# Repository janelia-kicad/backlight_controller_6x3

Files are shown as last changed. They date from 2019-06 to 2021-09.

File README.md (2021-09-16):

- [Repository Information](#org89e2f96)
  - [Description](#org01946da)
- [Images](#org5e6b005)
- [Schematic](#org50048ed)
- [Gerbers](#org1f83db4)
- [Bill of Materials](#org4e1d2f2)
  - [PCB Parts](#org0365191)
  - [Supplemental Parts](#org1217ce1)
  - [Vendor Parts Lists](#orge2d2bad)
- [Supplemental Documentation](#org1794ae5)
  - [Assembly Instructions](#orgcad51c4)
- [Manufacturing Archive](#orgdf269ab)

# Repository Information

-   **Name:** backlight\_controller\_6x3
-   **Version:** 1.0
-   **License:** Open-Source Hardware
-   **URL:** <https://github.com/janelia-kicad/backlight_controller_6x3>
-   **Author:** Peter Polidoro
-   **Email:** peter@polidoro.io

## Description

This board controls up to four Smart Vision backlights with IR and visible channels plus additional high and low power channel outputs.

# Images

# Schematic

[./schematic/backlight\_controller\_6x3.pdf](./schematic/backlight_controller_6x3.pdf)

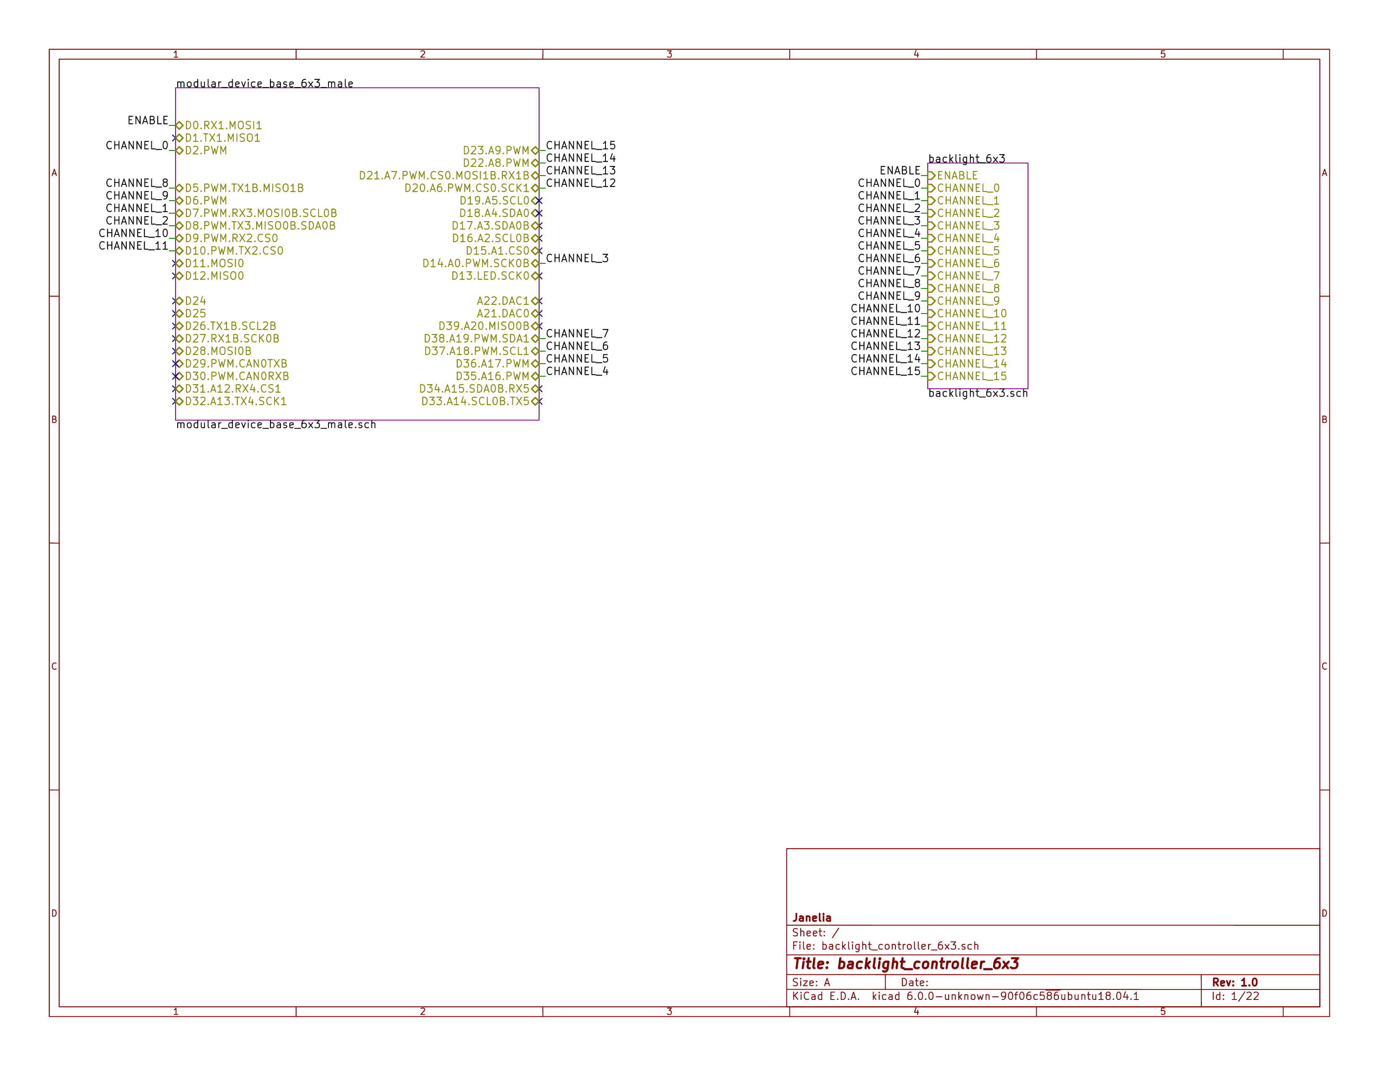
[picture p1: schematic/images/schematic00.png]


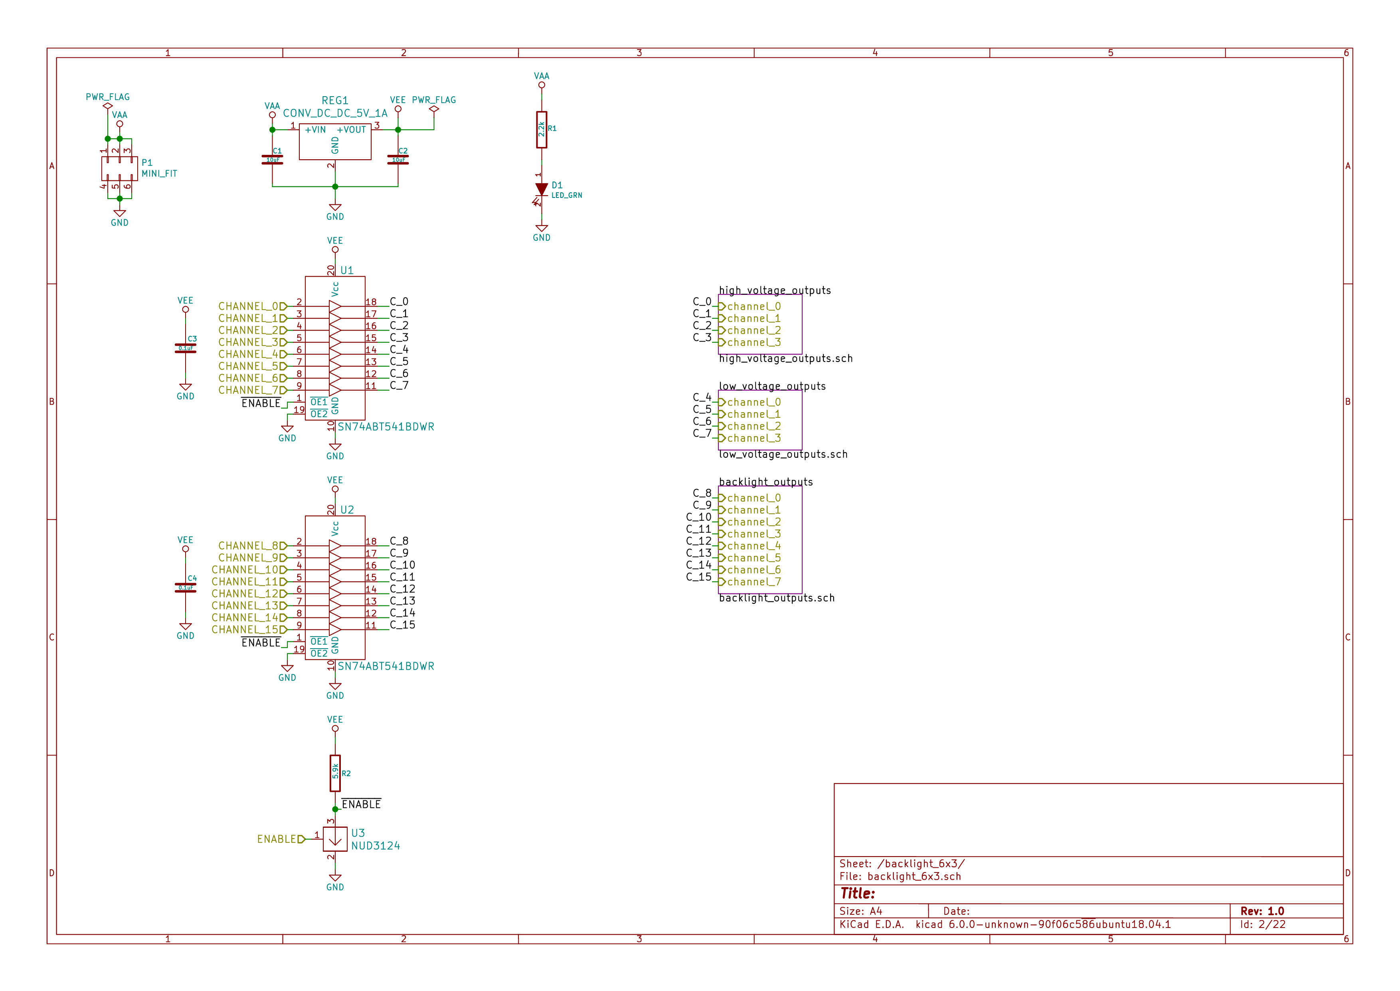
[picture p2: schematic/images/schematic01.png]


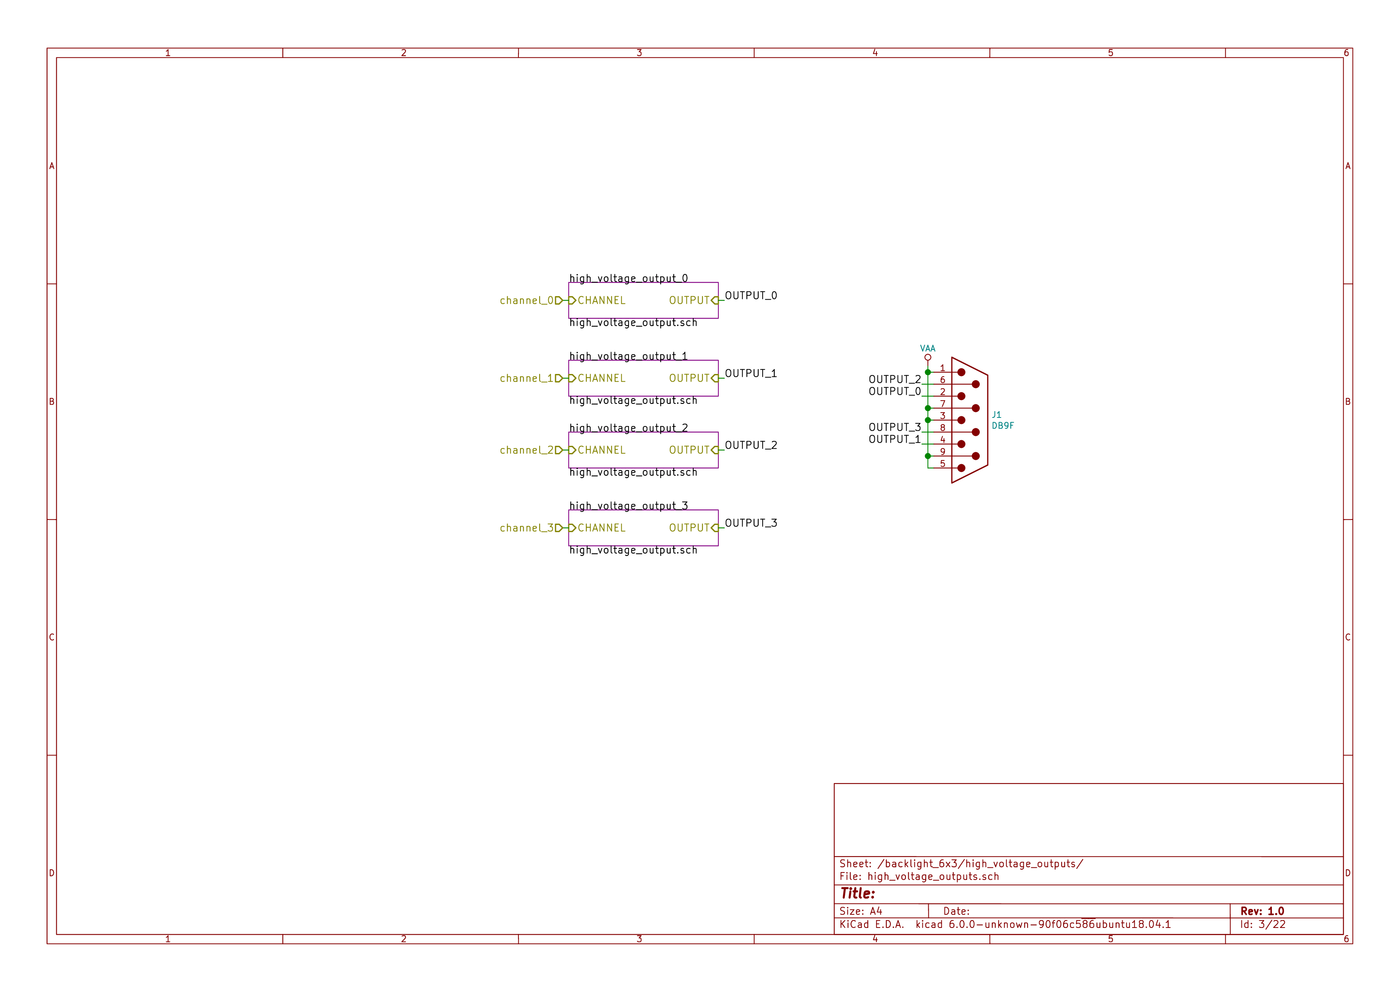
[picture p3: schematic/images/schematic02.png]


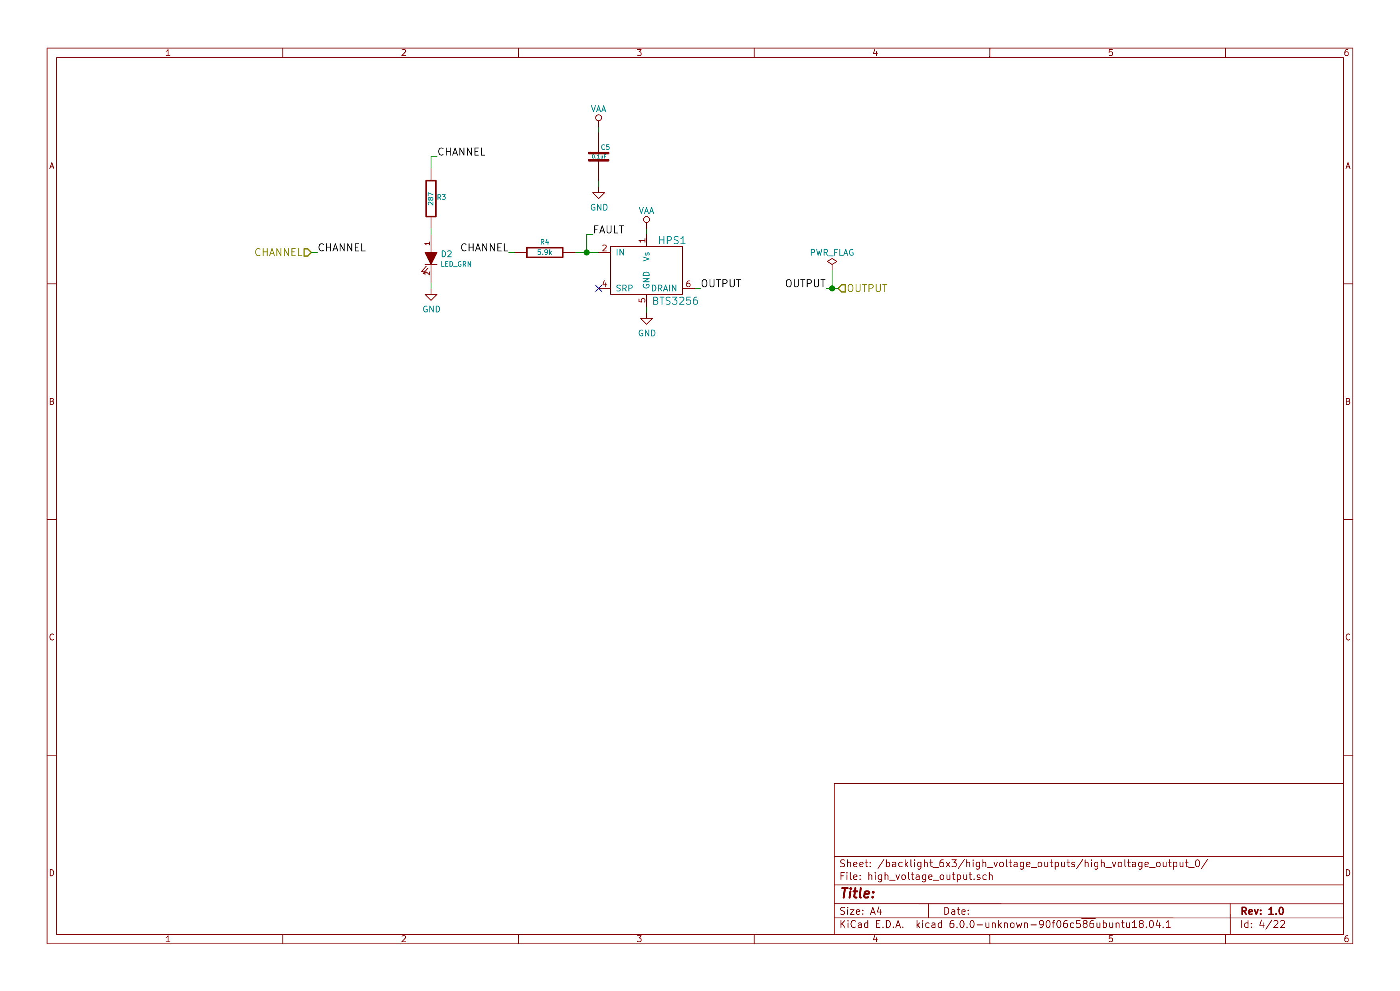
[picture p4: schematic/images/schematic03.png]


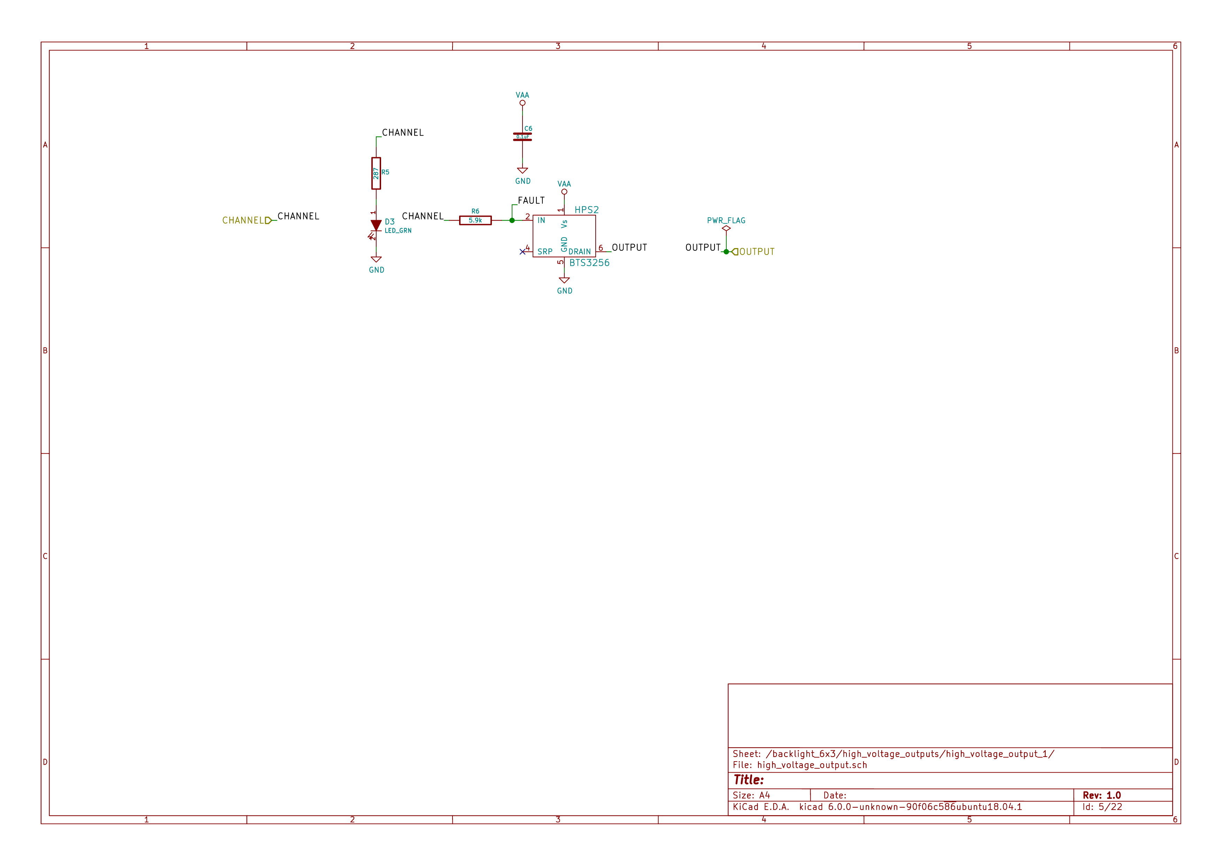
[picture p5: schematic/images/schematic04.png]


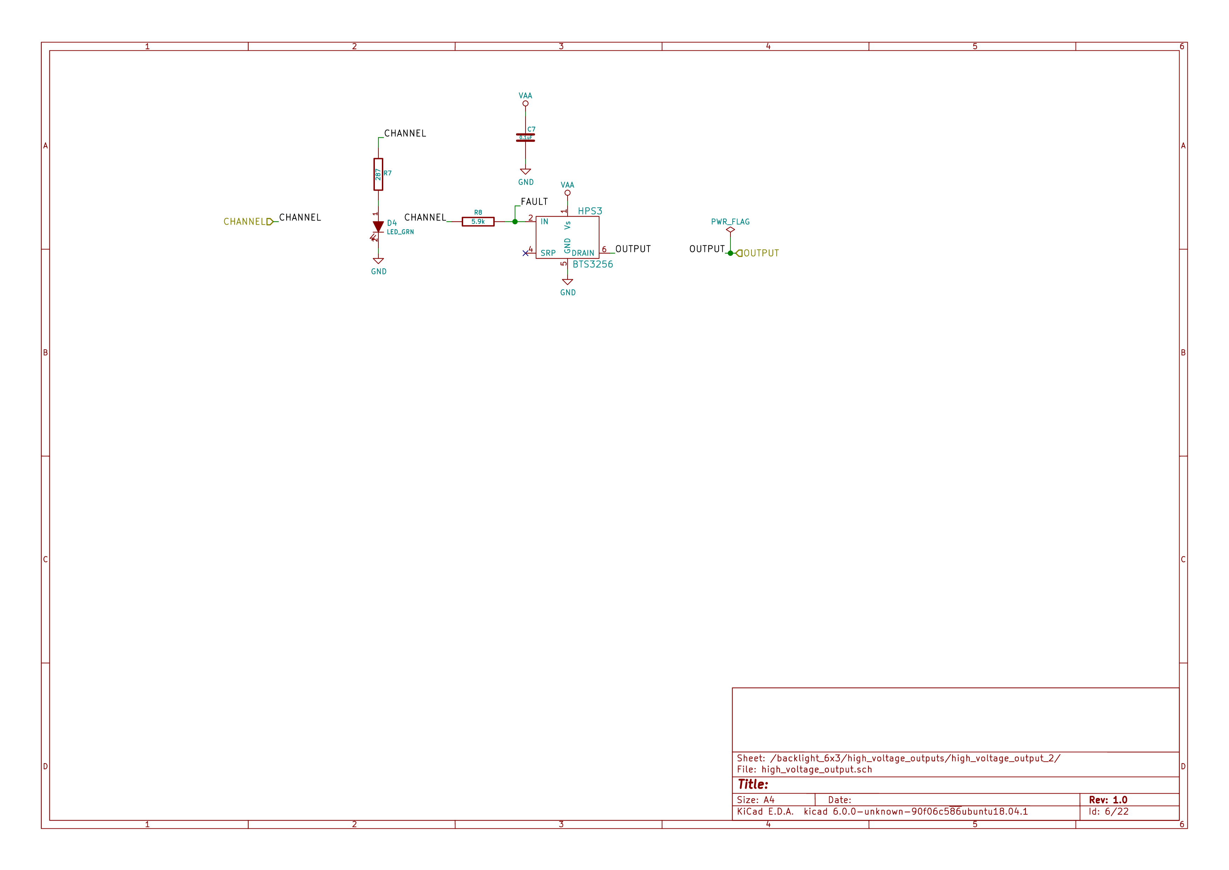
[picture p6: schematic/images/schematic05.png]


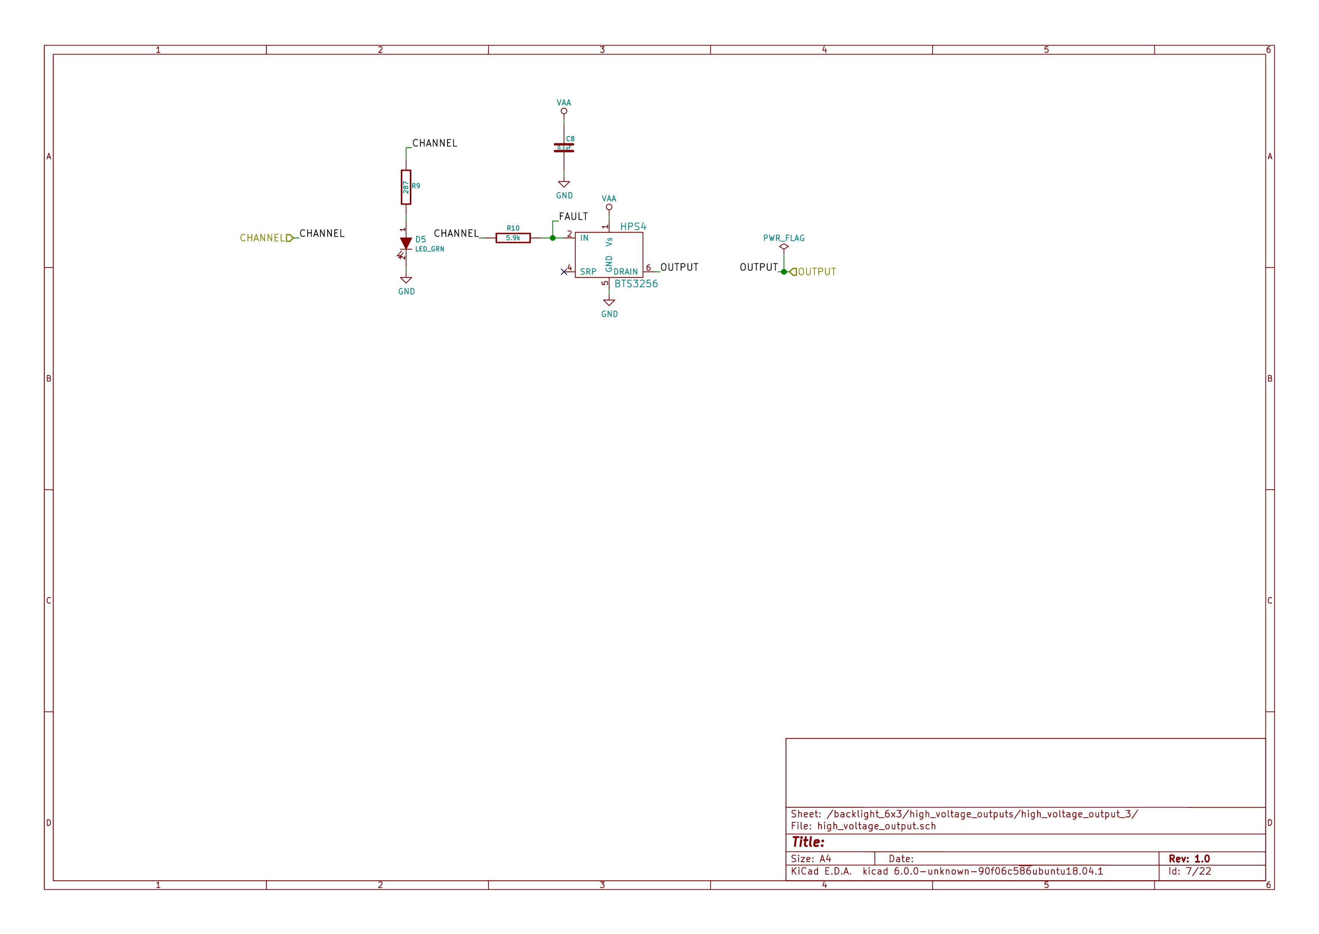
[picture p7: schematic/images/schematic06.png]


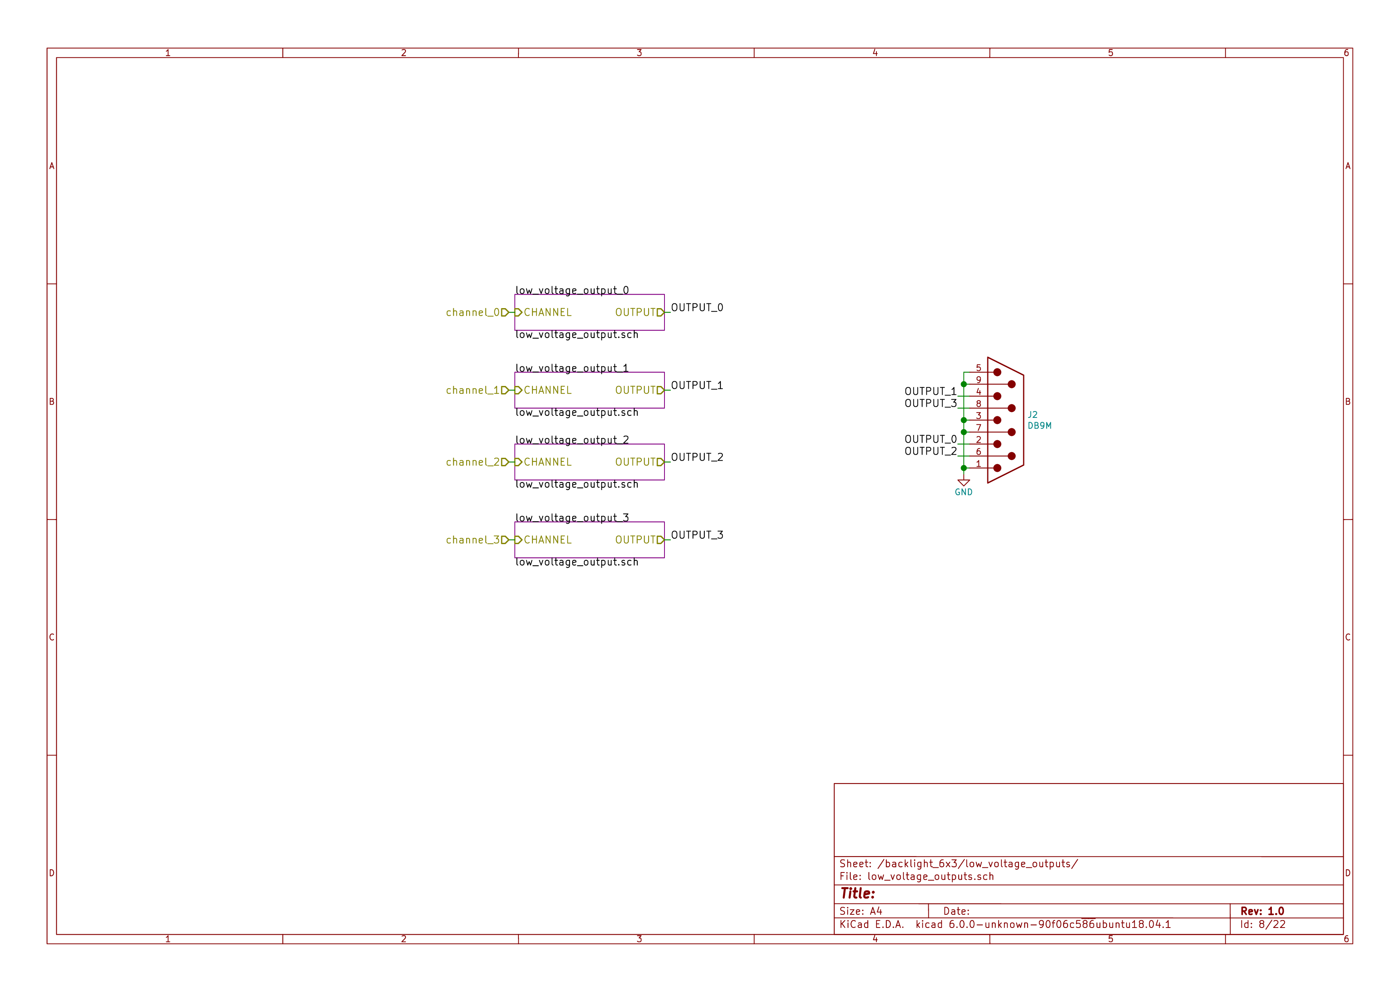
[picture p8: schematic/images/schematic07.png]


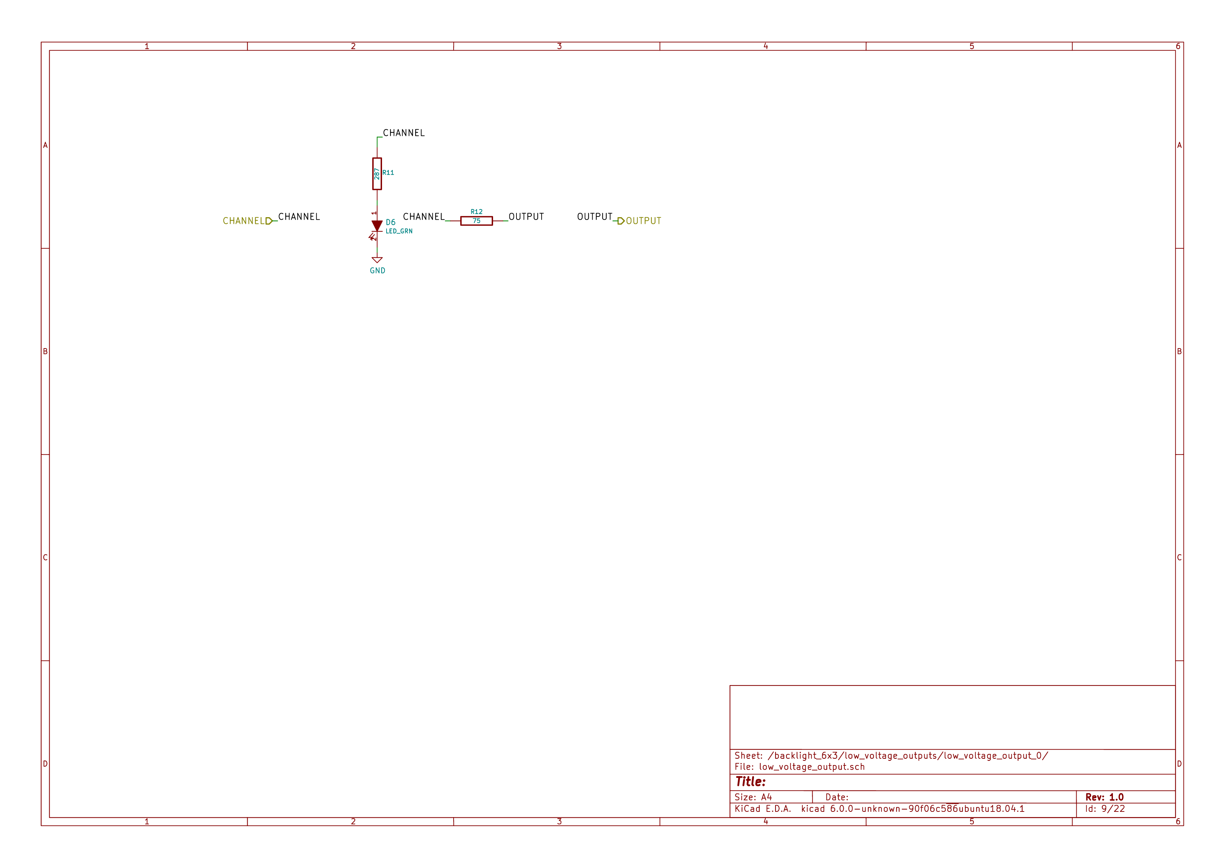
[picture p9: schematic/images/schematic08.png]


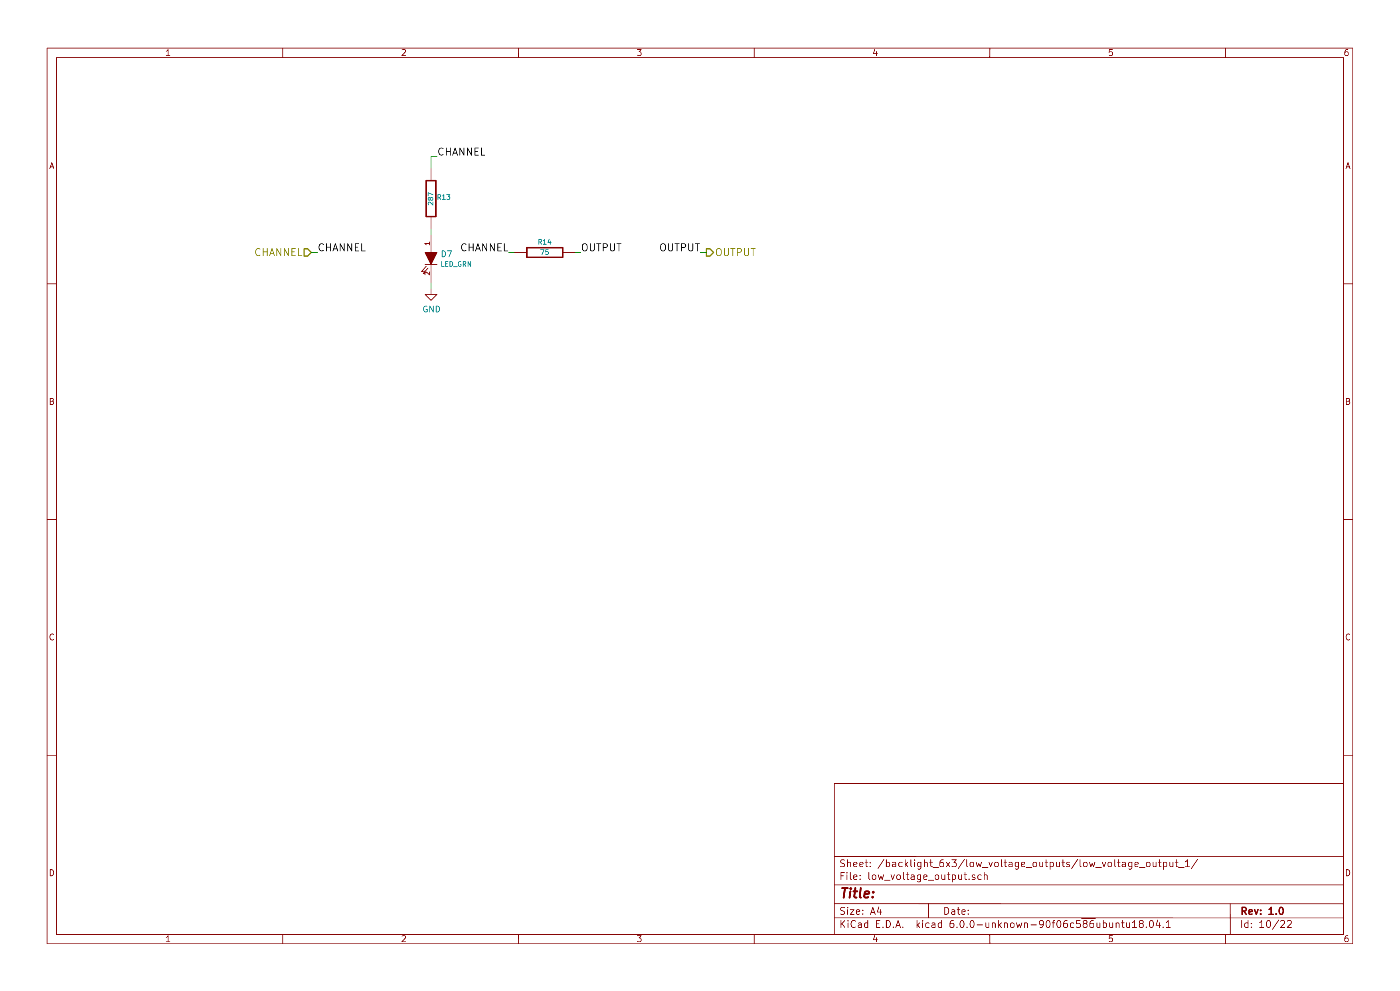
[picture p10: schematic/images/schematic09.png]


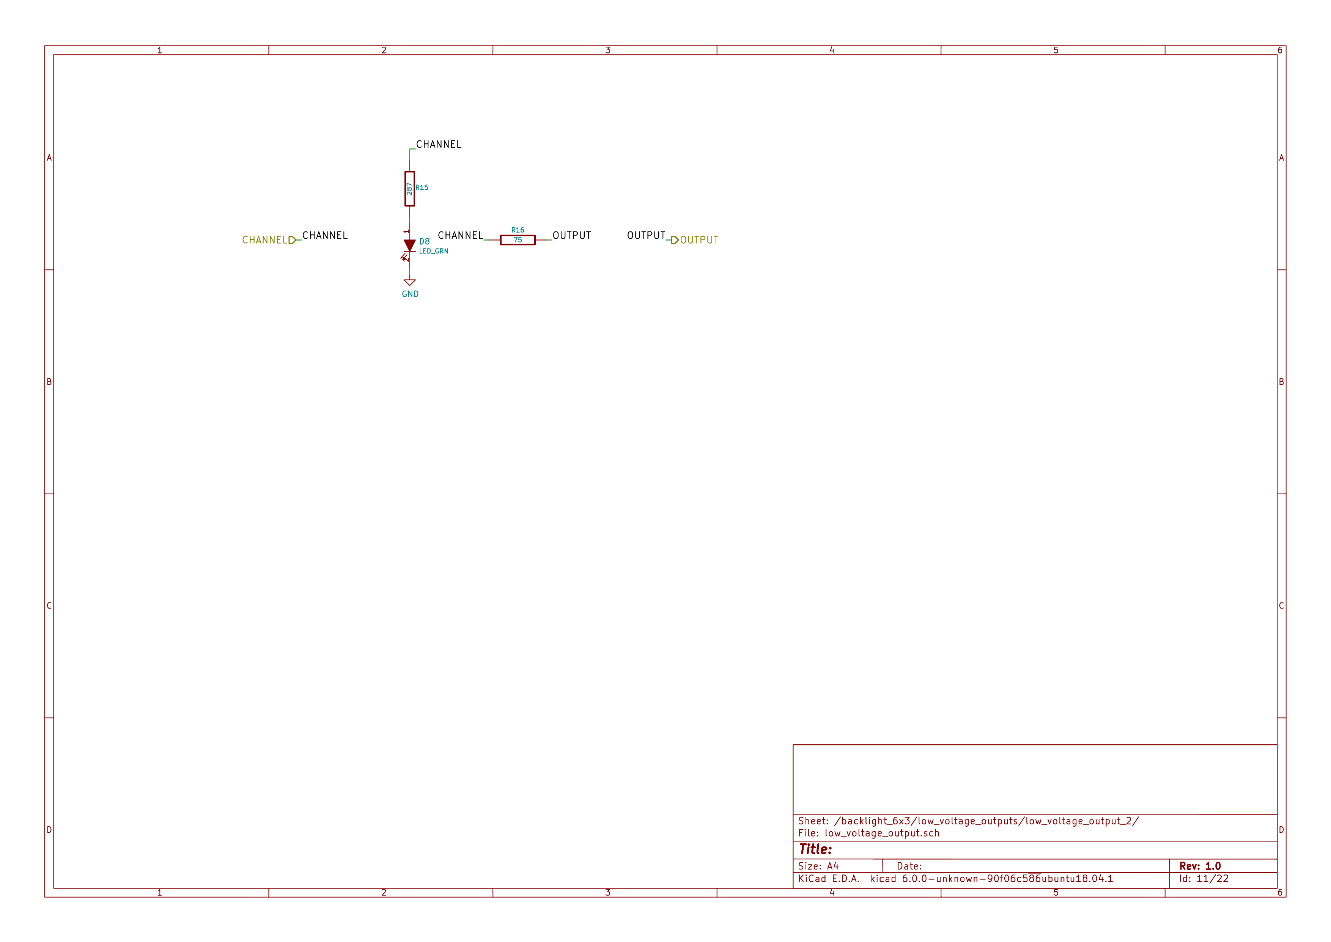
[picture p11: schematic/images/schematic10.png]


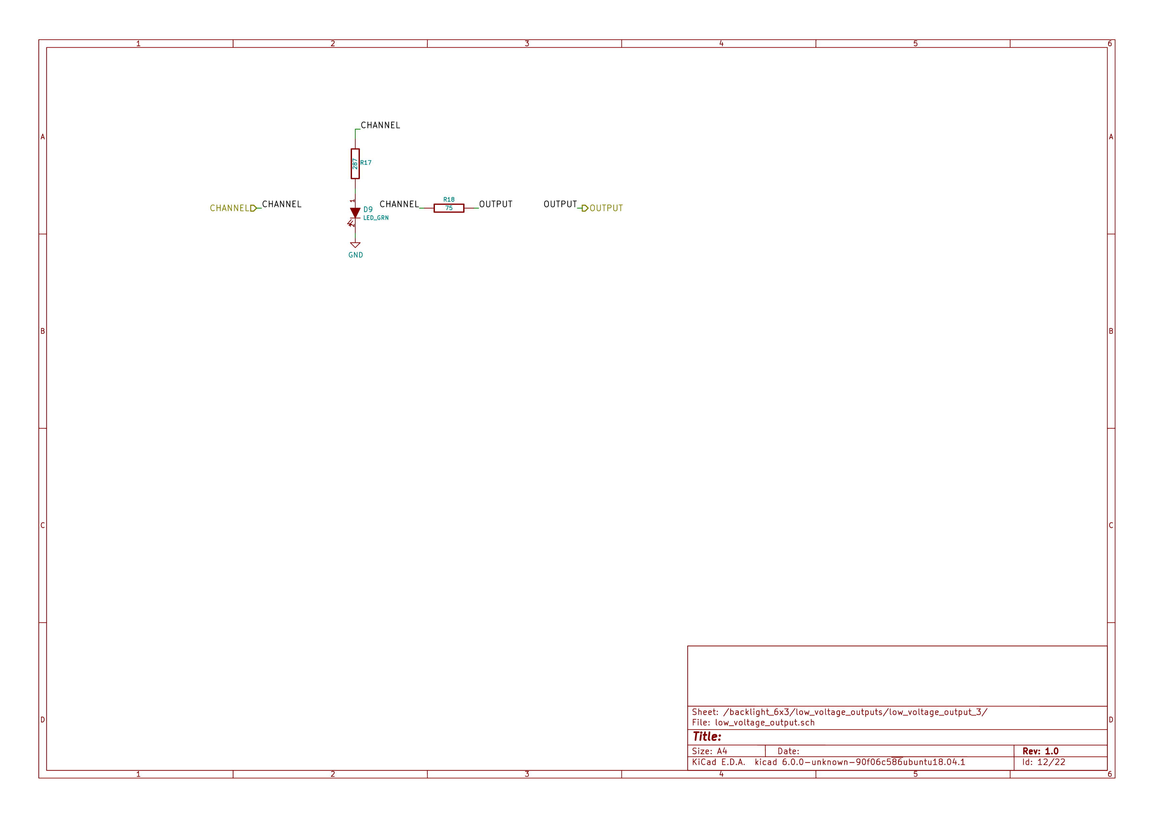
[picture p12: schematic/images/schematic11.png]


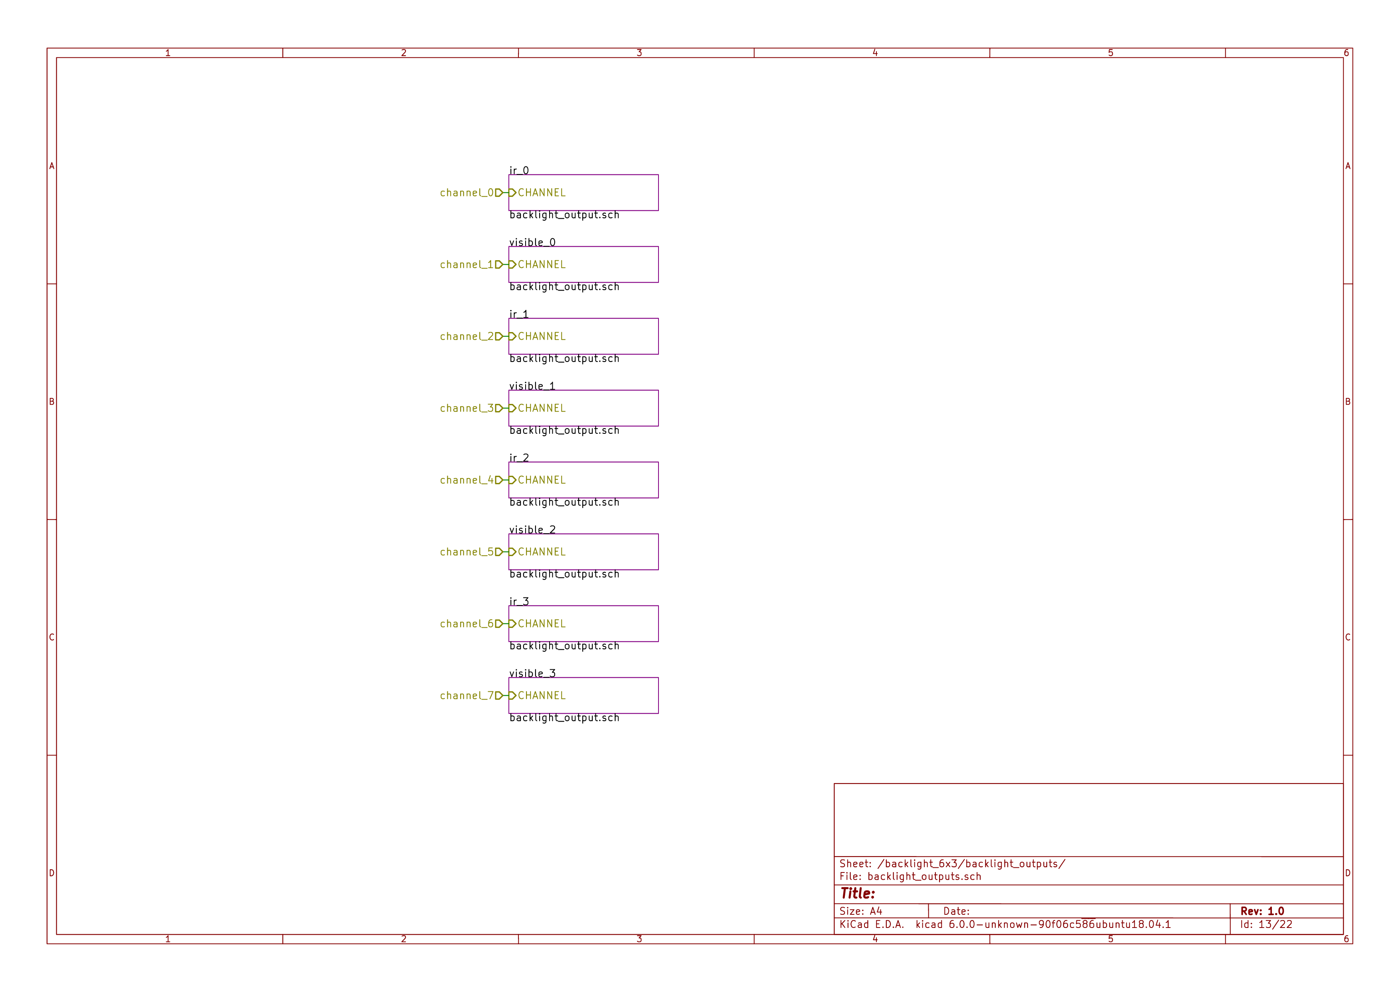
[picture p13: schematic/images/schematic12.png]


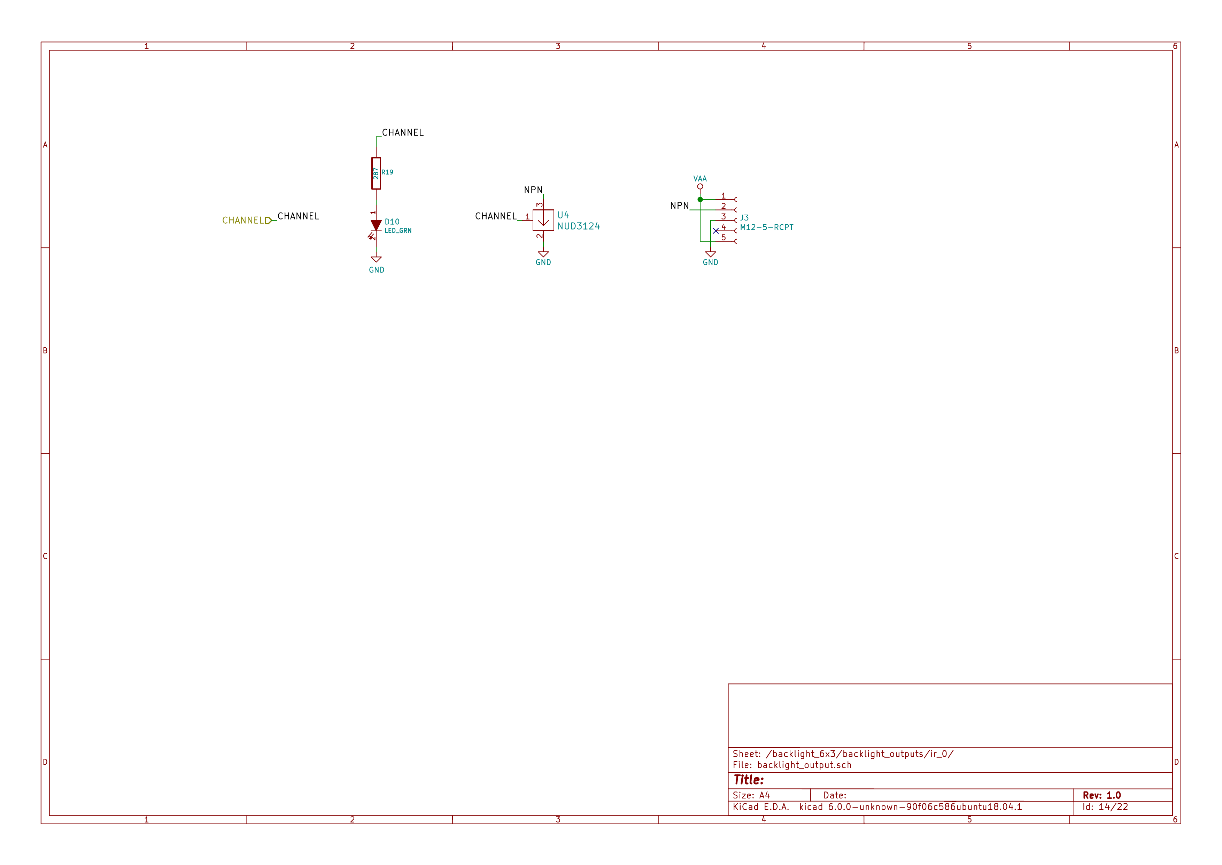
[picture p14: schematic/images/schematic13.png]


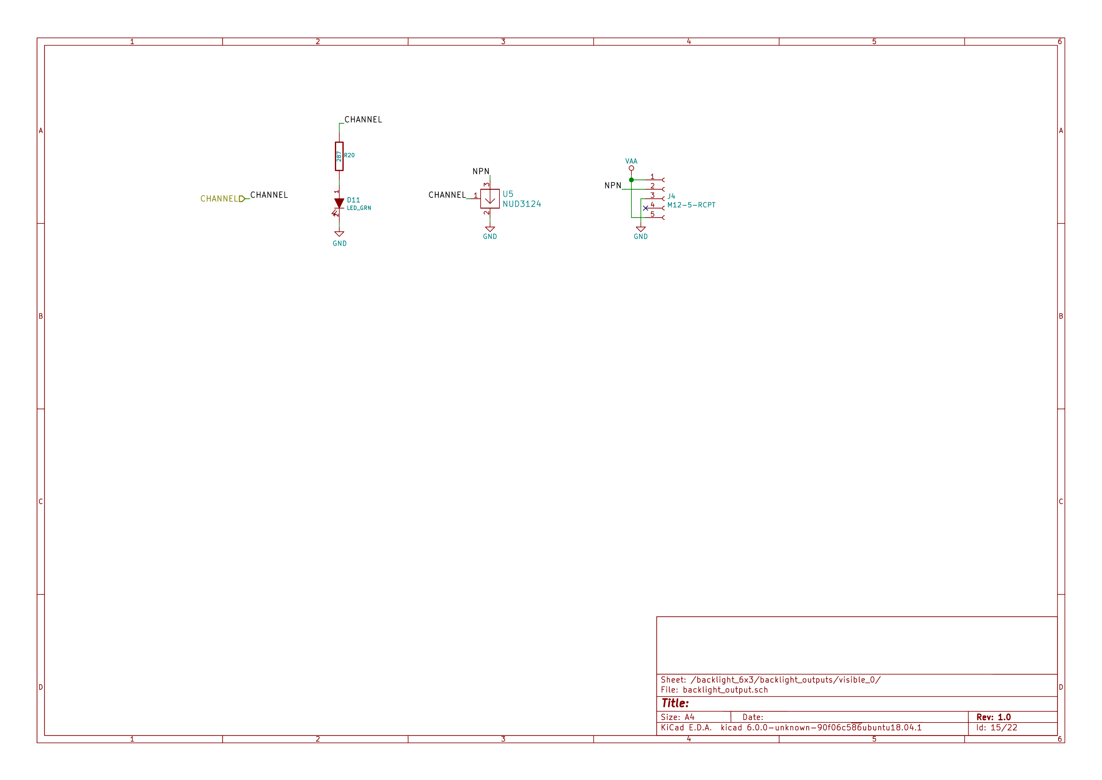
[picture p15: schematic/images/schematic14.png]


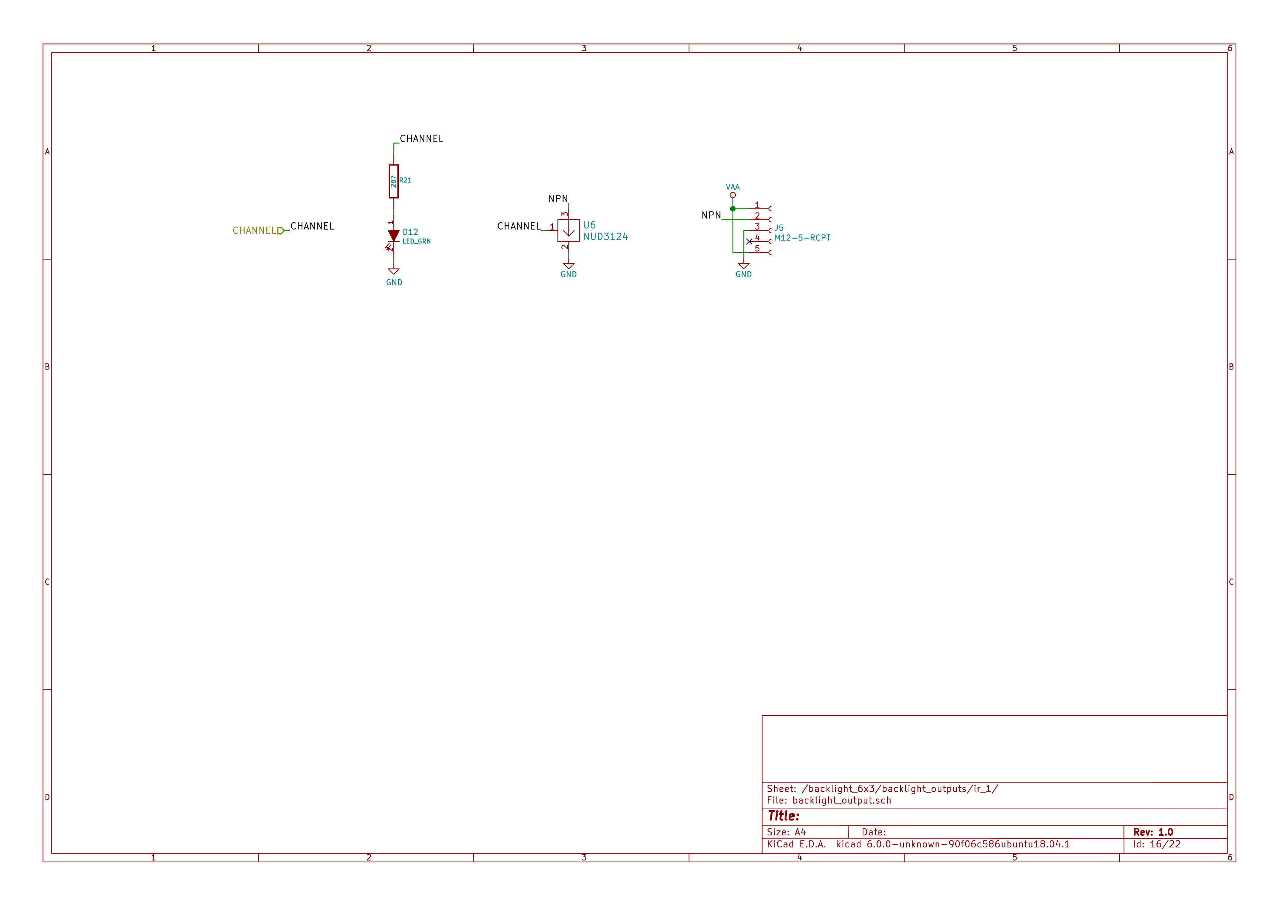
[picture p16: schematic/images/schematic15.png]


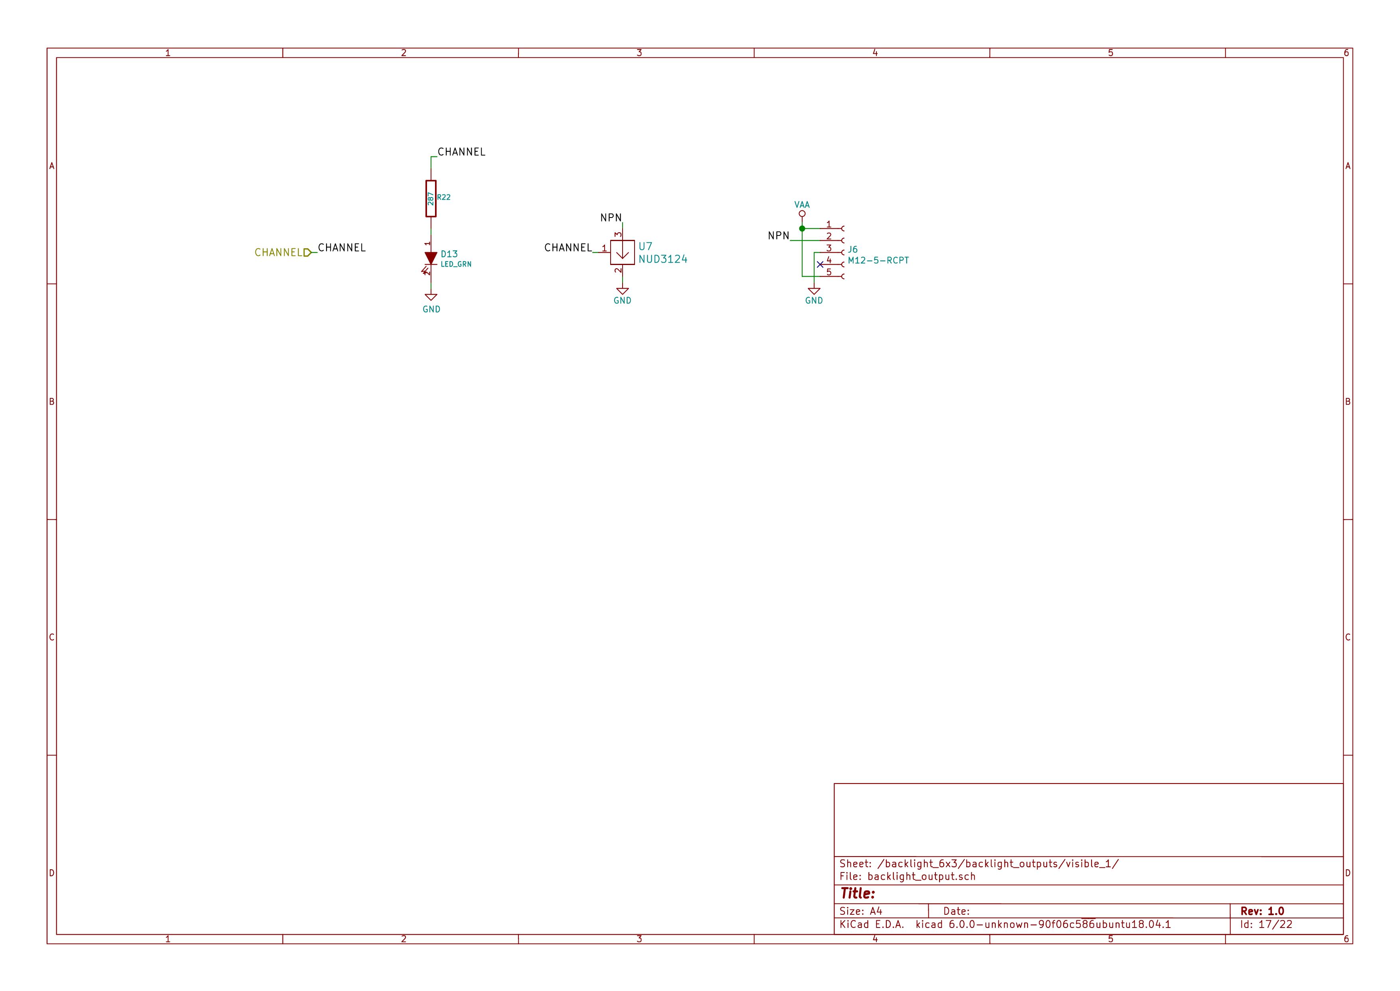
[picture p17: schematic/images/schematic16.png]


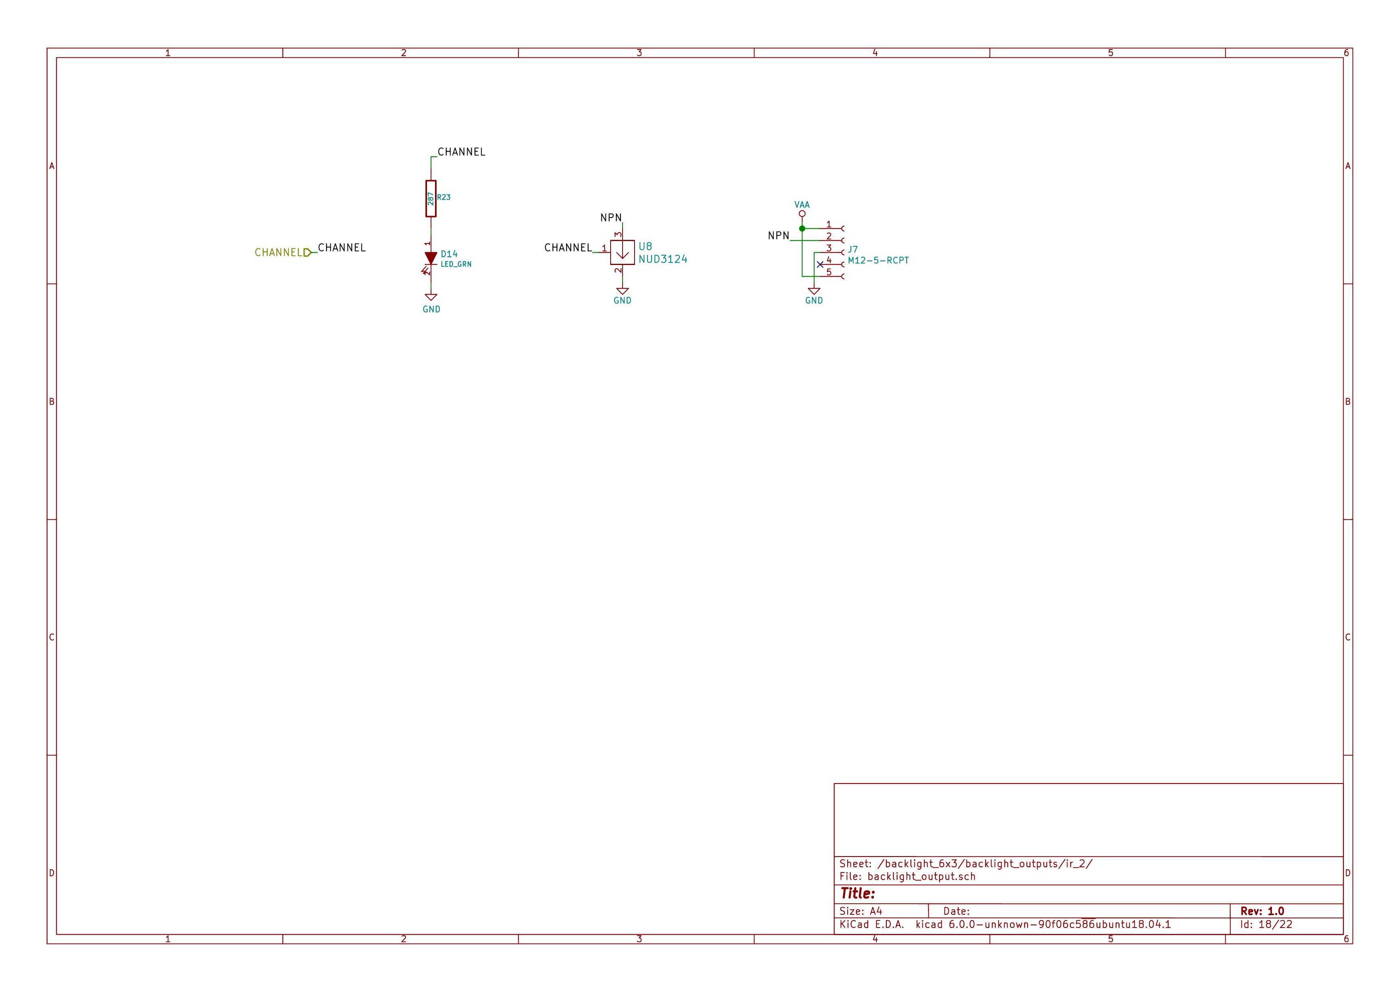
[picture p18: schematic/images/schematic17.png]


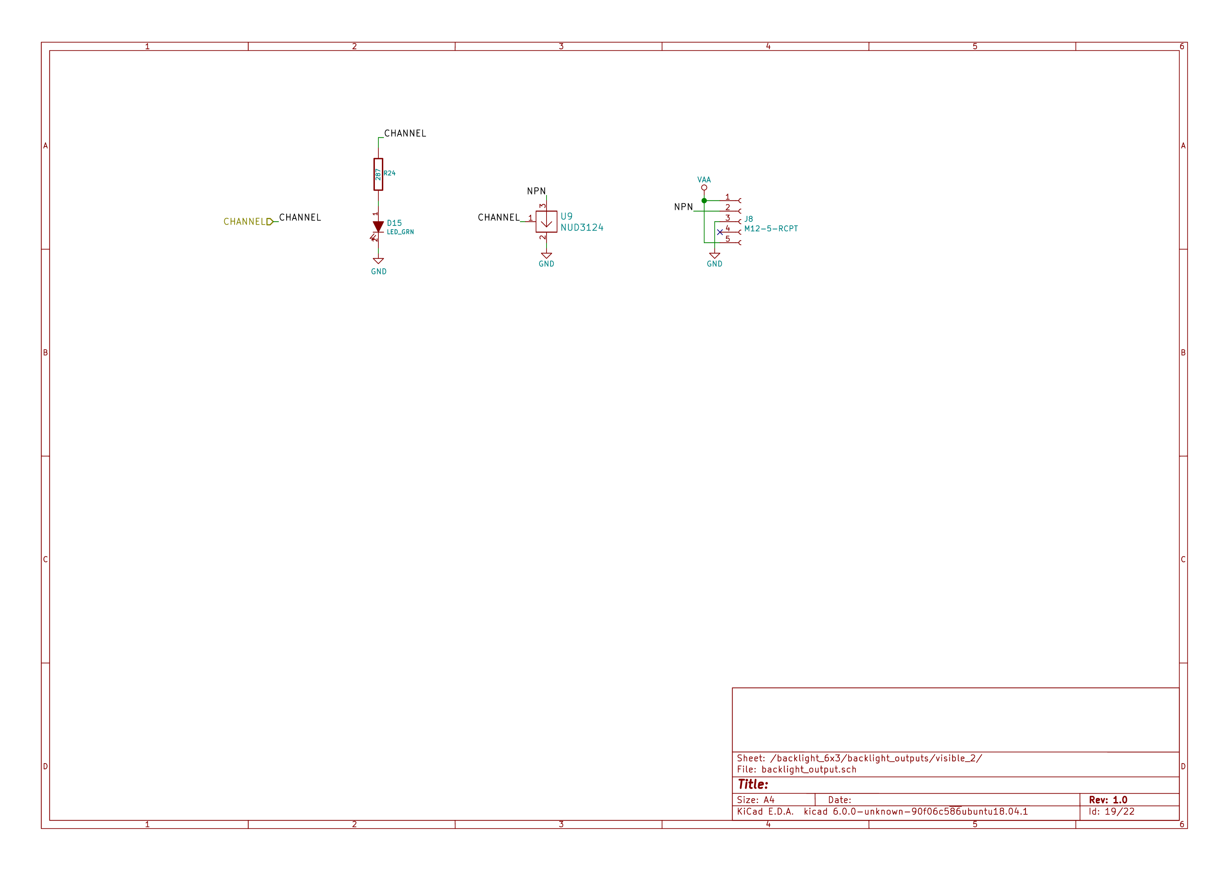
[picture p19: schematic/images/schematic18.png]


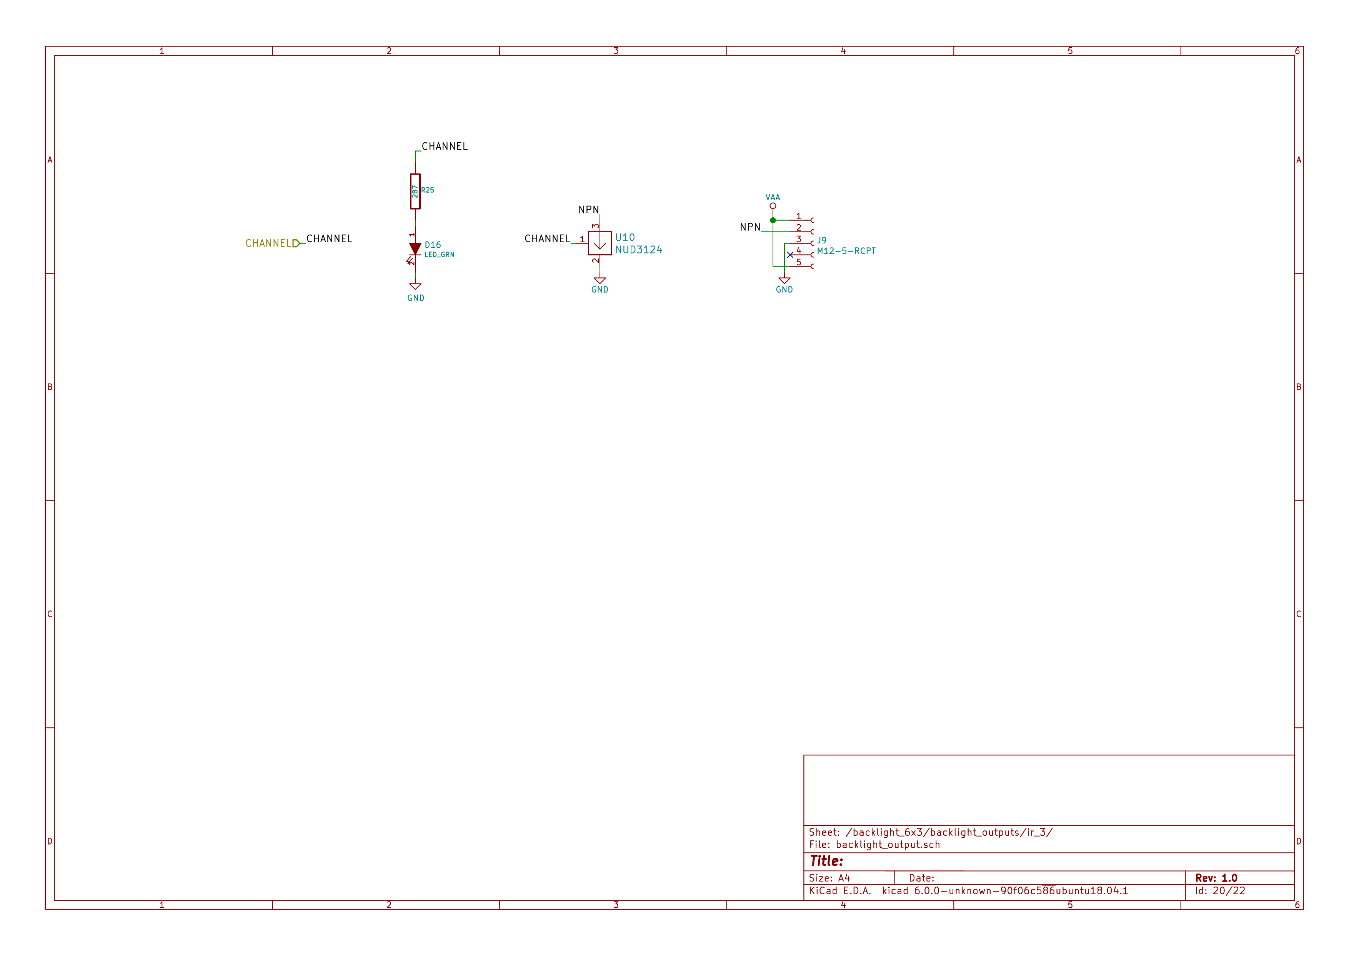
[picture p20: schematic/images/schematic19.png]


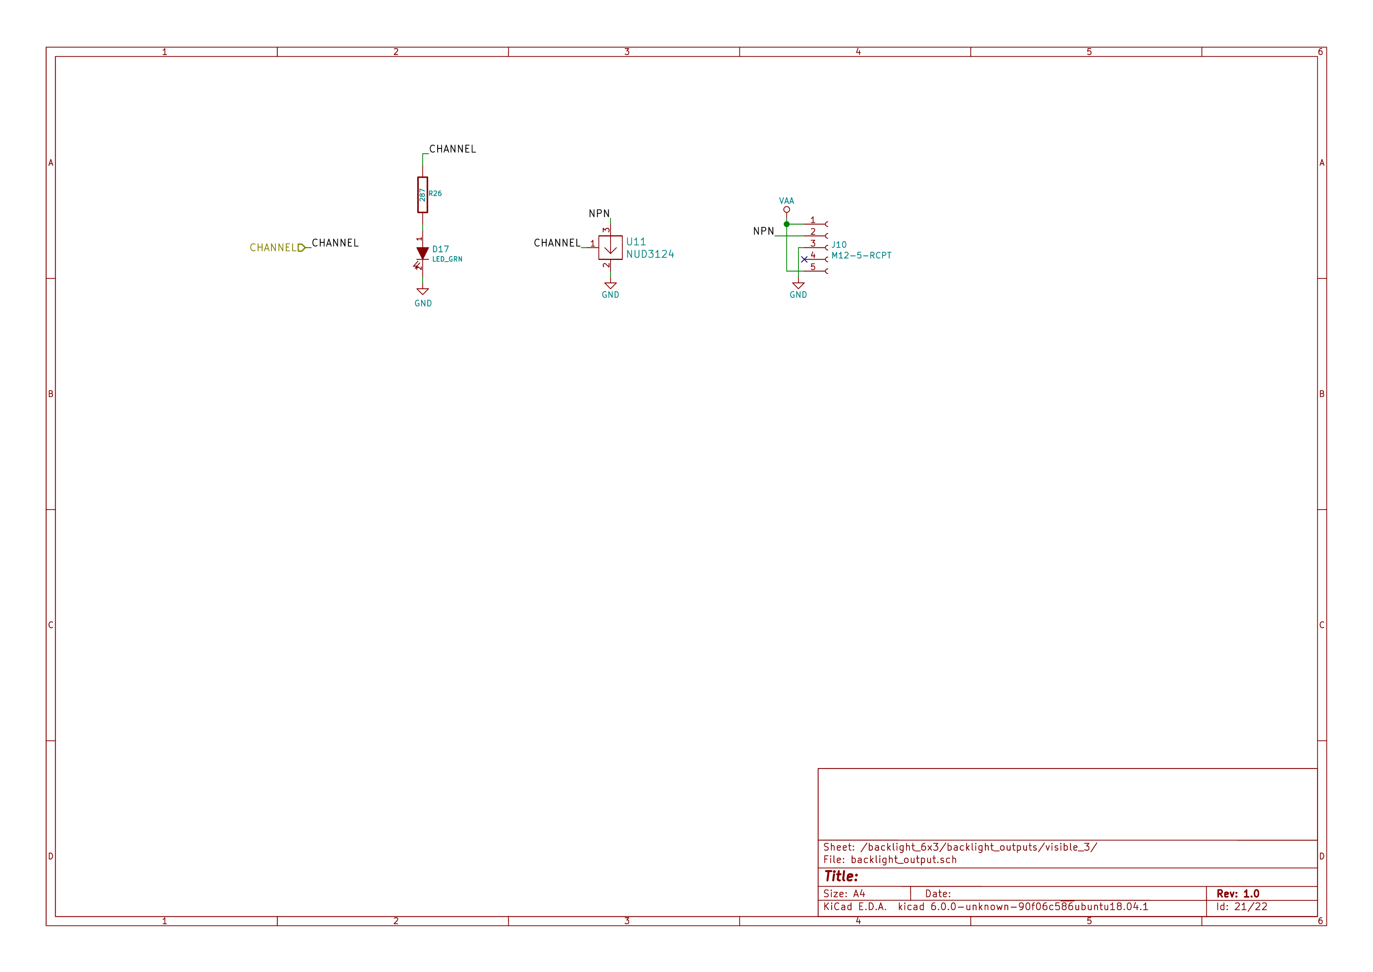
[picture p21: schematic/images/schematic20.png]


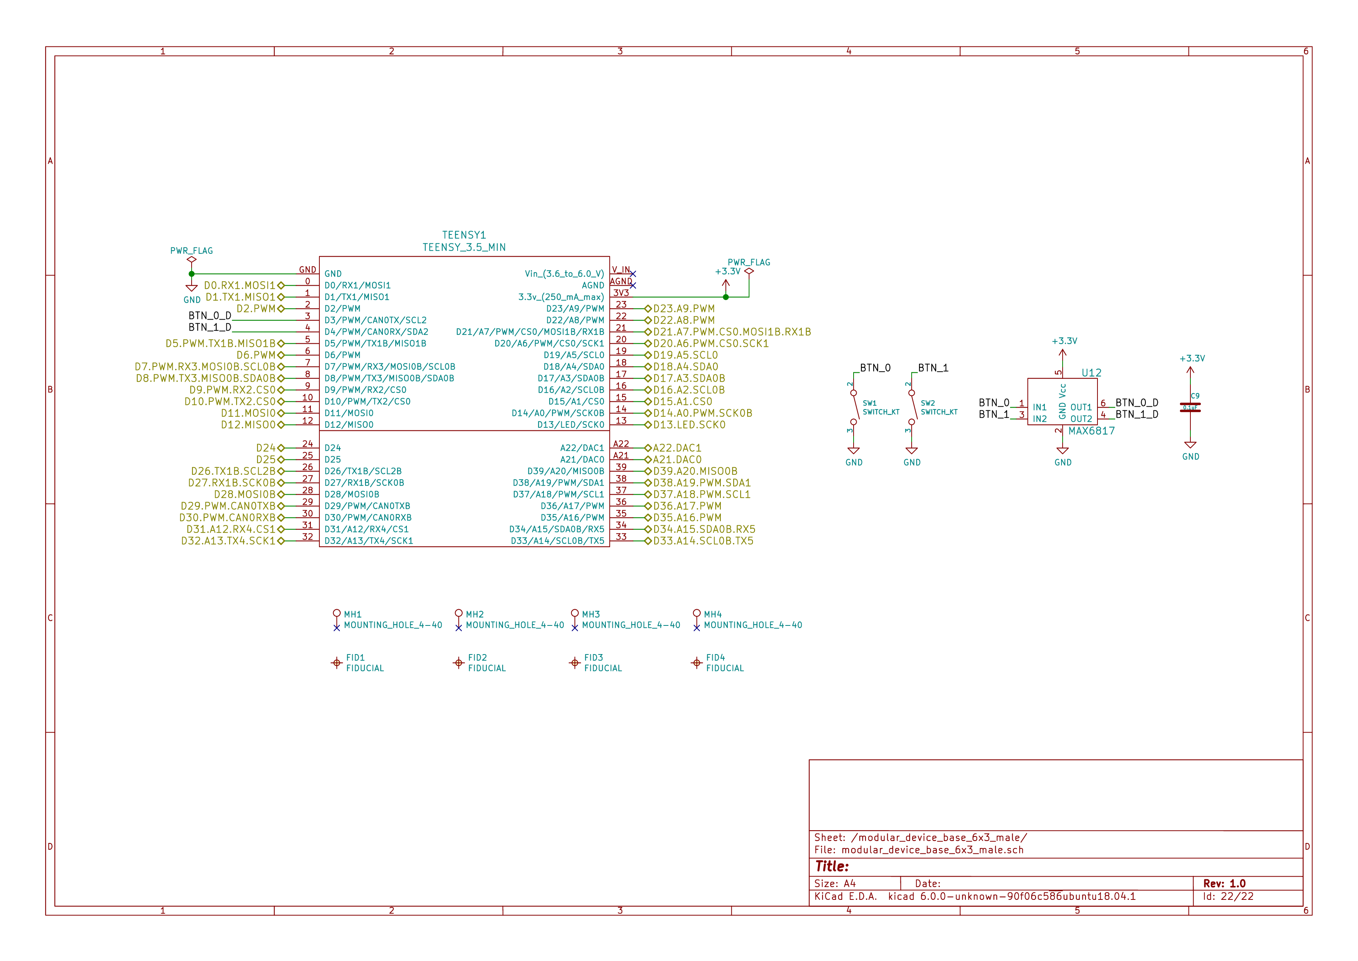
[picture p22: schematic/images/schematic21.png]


# Gerbers

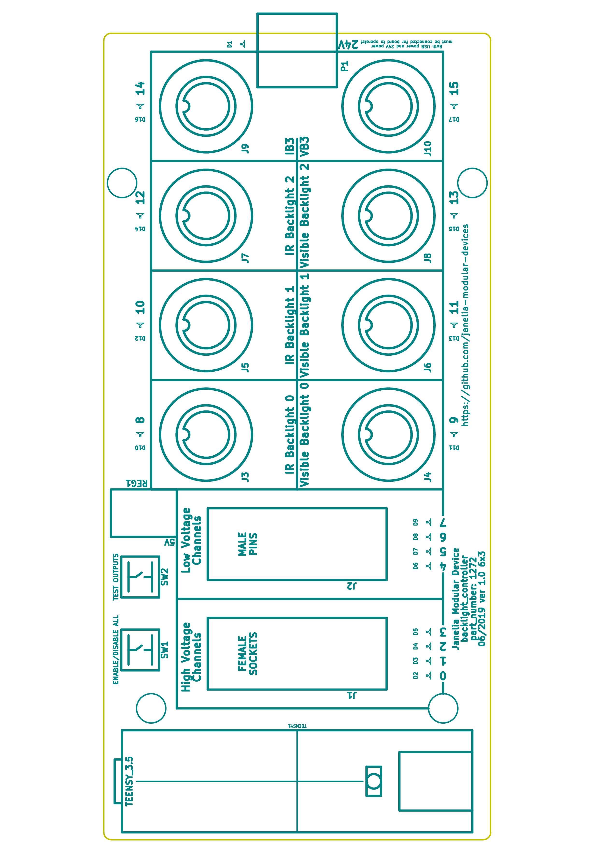
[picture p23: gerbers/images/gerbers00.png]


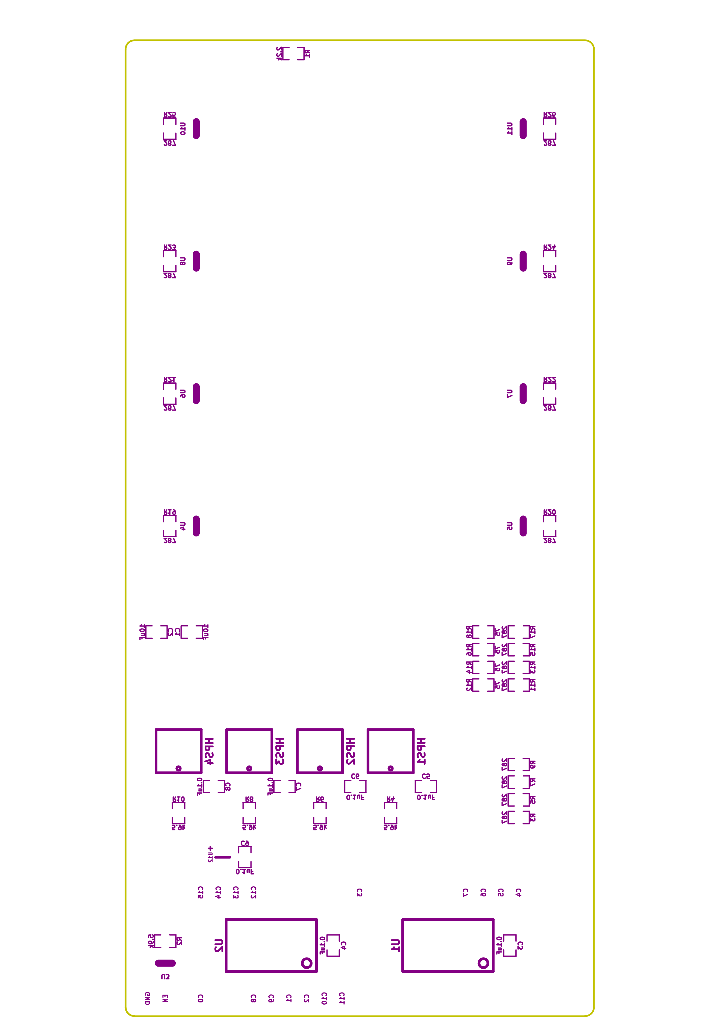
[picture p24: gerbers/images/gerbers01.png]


# Bill of Materials

## PCB Parts

| Item | Reference(s) | Quantity | Manufacturer Part Number | Description |
|---- |--- |--- |--- |--- |
| 1 | C1 C2 | 2 | C2012X5R1V106M085AC | CAP CER 10UF 35V X5R |
| 2 | C3 C4 C5 C6 C7 C8 C9 | 7 | C0805T104K5RAL7800 | CAP CER 0.1UF 50V X7R |
| 3 | D1 D10 D11 D12 D13 D14 D15 D16 D17 D2 D3 D4 D5 D6 D7 D8 D9  | 17 | LTST-C170GKT | LED GREEN CLEAR SMD |
| 4 | HPS1 HPS2 HPS3 HPS4 | 4 | BTS3256DAUMA1 | IC SWITCH SMART LOWSIDE |
| 5 | J1 | 1 | 09551156612741 | CONN D-SUB RCPT 9POS SMD SOLDER |
| 6 | J10 J3 J4 J5 J6 J7 J8 J9 | 8 | 1411976 | CONN FMALE INSERT 5POS SOLDER |
| 7 | J2 | 1 | 09551296812741 | CONN D-SUB PLUG 9POS SMD SOLDER |
| 8 | P1 | 1 | 0039301060 | CONN HEADER 6POS 4.2MM R/A TIN |
| 9 | R1 | 1 | ERJ-6ENF2201V | RES SMD 2.2K OHM 1% 1/8W |
| 10 | R10 R2 R4 R6 R8 | 5 | ERJ-6ENF5901V | RES SMD 5.9K OHM 1% 1/8W |
| 11 | R11 R13 R15 R17 R19 R20 R21 R22 R23 R24 R25 R26 R3 R5 R7 R9 | 16 | ERJ-6ENF2870V | RES SMD 287 OHM 1% 1/8W |
| 12 | R12 R14 R16 R18 | 4 | ERJ-6ENF75R0V | RES SMD 75 OHM 1% 1/8W |
| 13 | REG1 | 1 | R-78C5.0-1.0 | CONV DC/DC 1A 5V OUT SIP VERT |
| 14 | SW1 SW2 | 2 | KT11P4SM34LFS | SWITCH TACTILE SPST-NO 1VA 32V |
| 15 | TEENSY1 | 1 | DEV-14056 | TEENSY 3.5 HDRS K64 EVAL BRD |
| 16 | U1 U2 | 2 | SN74ABT541BDWR | Buffer Non-Inverting 1 Element 8 Bit per Element Push-Pull Output |
| 17 | U10 U11 U3 U4 U5 U6 U7 U8 U9 | 9 | NUD3124LT1G | IC INDCT LOAD DRVR AUTO |
| 18 | U12 | 1 | MAX6817EUT+T | IC DEBOUNCER SWITCH DUAL |

## Supplemental Parts

| Item | Quantity | Manufacturer Part Number | Description |
|---- |--- |--- |--- |
| 1 | 1 | GST280A24-C6P | AC/DC DESKTOP ADAPTER 24V 280W |
| 2 | 1 | CORD IEC 320-C13 6FT BLACK | CORD IEC 320-C13 6FT BLACK |

## Vendor Parts Lists

[./bom/Digi-Key\_parts.csv](./bom/Digi-Key_parts.csv)

[./bom/supplemental\_Digi-Key\_parts.csv](./bom/supplemental_Digi-Key_parts.csv)

# Supplemental Documentation

## Assembly Instructions

-   Solder surface mount and through hole components onto the pcb.

# Manufacturing Archive

Send manufacturing zip file to your favorite PCB manufacturer for fabrication.

[./manufacturing/backlight\_controller\_6x3\_v1.0.zip](./manufacturing/backlight_controller_6x3_v1.0.zip)

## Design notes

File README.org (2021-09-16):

# Created 2019-06-07 Fri 10:33
#+OPTIONS: title:nil author:nil email:nil toc:t |:t ^:nil
* Repository Information

- Name :: backlight_controller_6x3
- Version :: 1.0
- License :: Open-Source Hardware
- URL :: https://github.com/janelia-kicad/backlight_controller_6x3
- Author :: Peter Polidoro
- Email :: peter@polidoro.io

** Description

This board controls up to four Smart Vision backlights with IR and visible
channels plus additional high and low power channel outputs.

* Images

* Schematic

[[file:./schematic/backlight_controller_6x3.pdf][./schematic/backlight_controller_6x3.pdf]]













































* Gerbers





* Bill of Materials

** PCB Parts

| Item | Reference(s)                                                | Quantity | Manufacturer Part Number | Description                                                       |
|------+-------------------------------------------------------------+----------+--------------------------+-------------------------------------------------------------------|
|    1 | C1 C2                                                       |        2 | C2012X5R1V106M085AC      | CAP CER 10UF 35V X5R                                              |
|    2 | C3 C4 C5 C6 C7 C8 C9                                        |        7 | C0805T104K5RAL7800       | CAP CER 0.1UF 50V X7R                                             |
|    3 | D1 D10 D11 D12 D13 D14 D15 D16 D17 D2 D3 D4 D5 D6 D7 D8 D9  |       17 | LTST-C170GKT             | LED GREEN CLEAR SMD                                               |
|    4 | HPS1 HPS2 HPS3 HPS4                                         |        4 | BTS3256DAUMA1            | IC SWITCH SMART LOWSIDE                                           |
|    5 | J1                                                          |        1 | 09551156612741           | CONN D-SUB RCPT 9POS SMD SOLDER                                   |
|    6 | J10 J3 J4 J5 J6 J7 J8 J9                                    |        8 | 1411976                  | CONN FMALE INSERT 5POS SOLDER                                     |
|    7 | J2                                                          |        1 | 09551296812741           | CONN D-SUB PLUG 9POS SMD SOLDER                                   |
|    8 | P1                                                          |        1 | 0039301060               | CONN HEADER 6POS 4.2MM R/A TIN                                    |
|    9 | R1                                                          |        1 | ERJ-6ENF2201V            | RES SMD 2.2K OHM 1% 1/8W                                          |
|   10 | R10 R2 R4 R6 R8                                             |        5 | ERJ-6ENF5901V            | RES SMD 5.9K OHM 1% 1/8W                                          |
|   11 | R11 R13 R15 R17 R19 R20 R21 R22 R23 R24 R25 R26 R3 R5 R7 R9 |       16 | ERJ-6ENF2870V            | RES SMD 287 OHM 1% 1/8W                                           |
|   12 | R12 R14 R16 R18                                             |        4 | ERJ-6ENF75R0V            | RES SMD 75 OHM 1% 1/8W                                            |
|   13 | REG1                                                        |        1 | R-78C5.0-1.0             | CONV DC/DC 1A 5V OUT SIP VERT                                     |
|   14 | SW1 SW2                                                     |        2 | KT11P4SM34LFS            | SWITCH TACTILE SPST-NO 1VA 32V                                    |
|   15 | TEENSY1                                                     |        1 | DEV-14056                | TEENSY 3.5 HDRS K64 EVAL BRD                                      |
|   16 | U1 U2                                                       |        2 | SN74ABT541BDWR           | Buffer Non-Inverting 1 Element 8 Bit per Element Push-Pull Output |
|   17 | U10 U11 U3 U4 U5 U6 U7 U8 U9                                |        9 | NUD3124LT1G              | IC INDCT LOAD DRVR AUTO                                           |
|   18 | U12                                                         |        1 | MAX6817EUT+T             | IC DEBOUNCER SWITCH DUAL                                          |

** Supplemental Parts

| Item | Quantity | Manufacturer Part Number   | Description                    |
|------+----------+----------------------------+--------------------------------|
|    1 |        1 | GST280A24-C6P              | AC/DC DESKTOP ADAPTER 24V 280W |
|    2 |        1 | CORD IEC 320-C13 6FT BLACK | CORD IEC 320-C13 6FT BLACK     |

** Vendor Parts Lists

[[file:./bom/Digi-Key_parts.csv][./bom/Digi-Key_parts.csv]]

[[file:./bom/supplemental_Digi-Key_parts.csv][./bom/supplemental_Digi-Key_parts.csv]]

* Supplemental Documentation

** Assembly Instructions

- Solder surface mount and through hole components onto the pcb.

* Manufacturing Archive

Send manufacturing zip file to your favorite PCB manufacturer for fabrication.

[[file:./manufacturing/backlight_controller_6x3_v1.0.zip][./manufacturing/backlight_controller_6x3_v1.0.zip]]

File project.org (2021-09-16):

* Header                                                           :noexport:

  #+MACRO: name backlight_controller_6x3
  #+MACRO: version 1.0
  #+MACRO: license Open-Source Hardware
  #+MACRO: url https://github.com/janelia-kicad/backlight_controller_6x3
  #+AUTHOR: Peter Polidoro
  #+EMAIL: peter@polidoro.io

* Description

  This board controls up to four Smart Vision backlights with IR and visible
  channels plus additional high and low power channel outputs.

* Assembly Instructions

  - Solder surface mount and through hole components onto the pcb.

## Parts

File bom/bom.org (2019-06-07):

# Created 2019-06-07 Fri 10:33
* Bill of Materials
#+RESULTS: pcb-parts
| Item | Reference(s)                                                | Quantity | Manufacturer                    | Manufacturer Part Number | Vendor   | Vendor Part Number | Description                                                       | Package            |
|------+-------------------------------------------------------------+----------+---------------------------------+--------------------------+----------+--------------------+-------------------------------------------------------------------+--------------------|
|    1 | C1 C2                                                       |        2 | TDK Corporation                 | C2012X5R1V106M085AC      | Digi-Key | 445-14419-1-ND     | CAP CER 10UF 35V X5R                                              | 0805 (2012 Metric) |
|    2 | C3 C4 C5 C6 C7 C8 C9                                        |        7 | KEMET                           | C0805T104K5RAL7800       | Digi-Key | 399-14636-1-ND     | CAP CER 0.1UF 50V X7R                                             | 0805 (2012 Metric) |
|    3 | D1 D10 D11 D12 D13 D14 D15 D16 D17 D2 D3 D4 D5 D6 D7 D8 D9  |       17 | Lite-On Inc.                    | LTST-C170GKT             | Digi-Key | 160-1179-1-ND      | LED GREEN CLEAR SMD                                               | 0805 (2012 Metric) |
|    4 | HPS1 HPS2 HPS3 HPS4                                         |        4 | Infineon Technologies           | BTS3256DAUMA1            | Digi-Key | BTS3256DAUMA1CT-ND | IC SWITCH SMART LOWSIDE                                           | TO-252-5           |
|    5 | J1                                                          |        1 | HARTING                         | 09551156612741           | Digi-Key | 1195-4005-1-ND     | CONN D-SUB RCPT 9POS SMD SOLDER                                   |                    |
|    6 | J10 J3 J4 J5 J6 J7 J8 J9                                    |        8 | Phoenix Contact                 | 1411976                  | Digi-Key | 277-10282-1-ND     | CONN FMALE INSERT 5POS SOLDER                                     |                    |
|    7 | J2                                                          |        1 | HARTING                         | 09551296812741           | Digi-Key | 1195-4006-1-ND     | CONN D-SUB PLUG 9POS SMD SOLDER                                   |                    |
|    8 | P1                                                          |        1 | Molex                           | 0039301060               | Digi-Key | WM1353-ND          | CONN HEADER 6POS 4.2MM R/A TIN                                    |                    |
|    9 | R1                                                          |        1 | Panasonic Electronic Components | ERJ-6ENF2201V            | Digi-Key | P2.20KCCT-ND       | RES SMD 2.2K OHM 1% 1/8W                                          | 0805 (2012 Metric) |
|   10 | R10 R2 R4 R6 R8                                             |        5 | Panasonic Electronic Components | ERJ-6ENF5901V            | Digi-Key | P5.90KCCT-ND       | RES SMD 5.9K OHM 1% 1/8W                                          | 0805 (2012 Metric) |
|   11 | R11 R13 R15 R17 R19 R20 R21 R22 R23 R24 R25 R26 R3 R5 R7 R9 |       16 | Panasonic Electronic Components | ERJ-6ENF2870V            | Digi-Key | P287CCT-ND         | RES SMD 287 OHM 1% 1/8W                                           | 0805 (2012 Metric) |
|   12 | R12 R14 R16 R18                                             |        4 | Panasonic Electronic Components | ERJ-6ENF75R0V            | Digi-Key | P75.0CCT-ND        | RES SMD 75 OHM 1% 1/8W                                            | 0805 (2012 Metric) |
|   13 | REG1                                                        |        1 | Recom Power                     | R-78C5.0-1.0             | Digi-Key | 945-1395-5-ND      | CONV DC/DC 1A 5V OUT SIP VERT                                     | 3-SIP Module       |
|   14 | SW1 SW2                                                     |        2 | C&K                             | KT11P4SM34LFS            | Digi-Key | CKN1860CT-ND       | SWITCH TACTILE SPST-NO 1VA 32V                                    |                    |
|   15 | TEENSY1                                                     |        1 | SparkFun Electronics            | DEV-14056                | Digi-Key | 1568-1464-ND       | TEENSY 3.5 HDRS K64 EVAL BRD                                      |                    |
|   16 | U1 U2                                                       |        2 | Texas Instruments               | SN74ABT541BDWR           | Digi-Key | 296-14668-1-ND     | Buffer Non-Inverting 1 Element 8 Bit per Element Push-Pull Output | 20-SOIC            |
|   17 | U10 U11 U3 U4 U5 U6 U7 U8 U9                                |        9 | ON Semiconductor                | NUD3124LT1G              | Digi-Key | NUD3124LT1GOSCT-ND | IC INDCT LOAD DRVR AUTO                                           | SOT-23-3           |
|   18 | U12                                                         |        1 | Maxim Integrated                | MAX6817EUT+T             | Digi-Key | MAX6817EUT+TCT-ND  | IC DEBOUNCER SWITCH DUAL                                          | SOT-23-6           |

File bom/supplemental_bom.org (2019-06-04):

* Supplemental Bill of Materials
#+RESULTS: supplemental-parts
| Item | Quantity | Manufacturer       | Manufacturer Part Number   | Vendor   | Vendor Part Number | Description                    |
|------+----------+--------------------+----------------------------+----------+--------------------+--------------------------------|
|    1 |        1 | MEAN WELL USA Inc. | GST280A24-C6P              | Digi-Key | 1866-2122-ND       | AC/DC DESKTOP ADAPTER 24V 280W |
|    2 |        1 | MEAN WELL USA Inc. | CORD IEC 320-C13 6FT BLACK | Digi-Key | 1866-5006-ND       | CORD IEC 320-C13 6FT BLACK     |

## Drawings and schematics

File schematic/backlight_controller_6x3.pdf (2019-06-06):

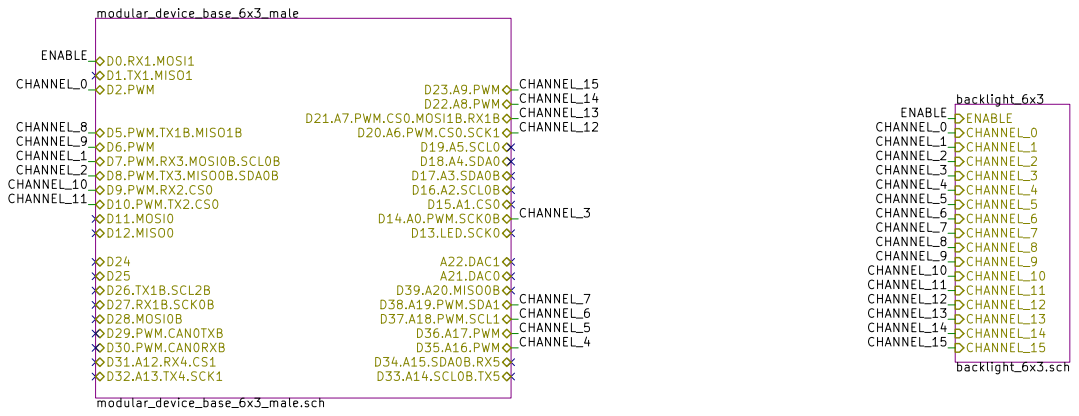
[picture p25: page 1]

File: backlight_controller_6x3.sch Sheet: / Janelia

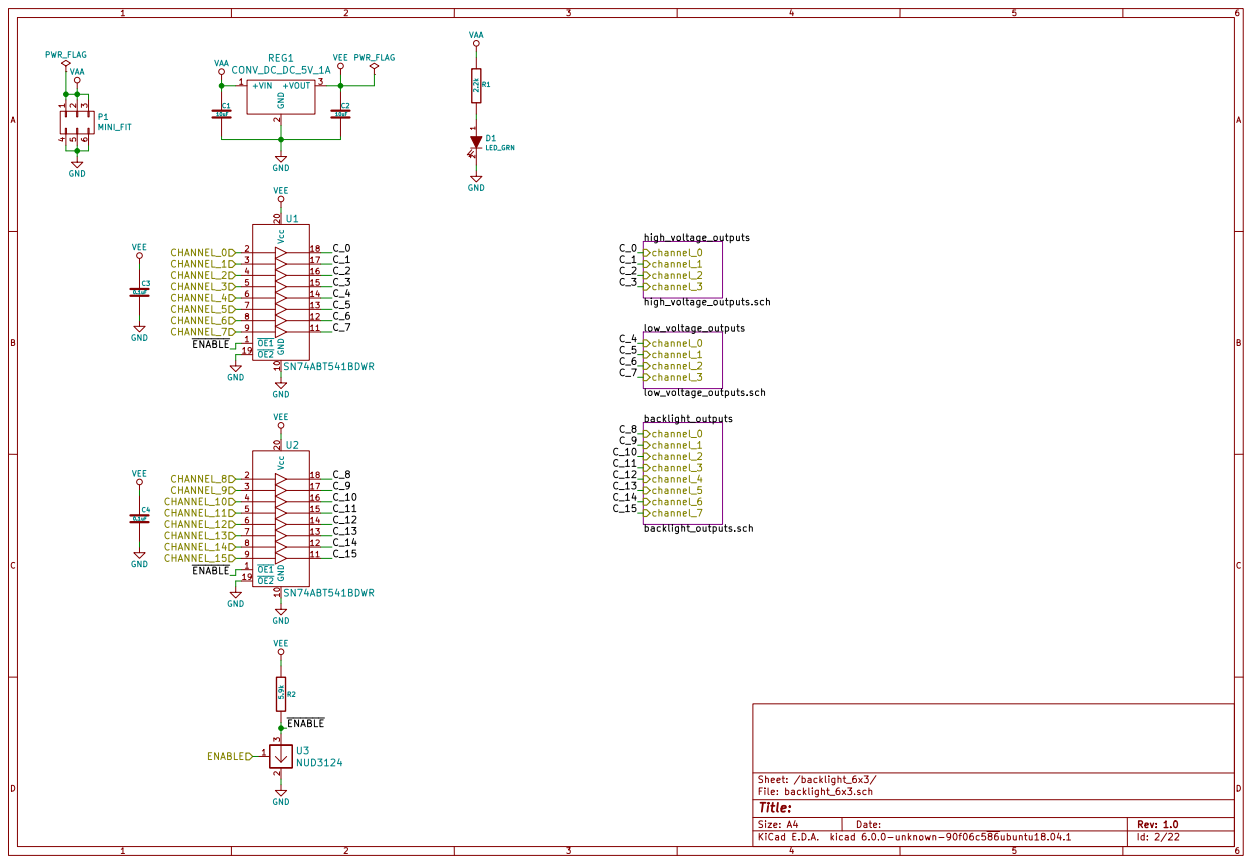
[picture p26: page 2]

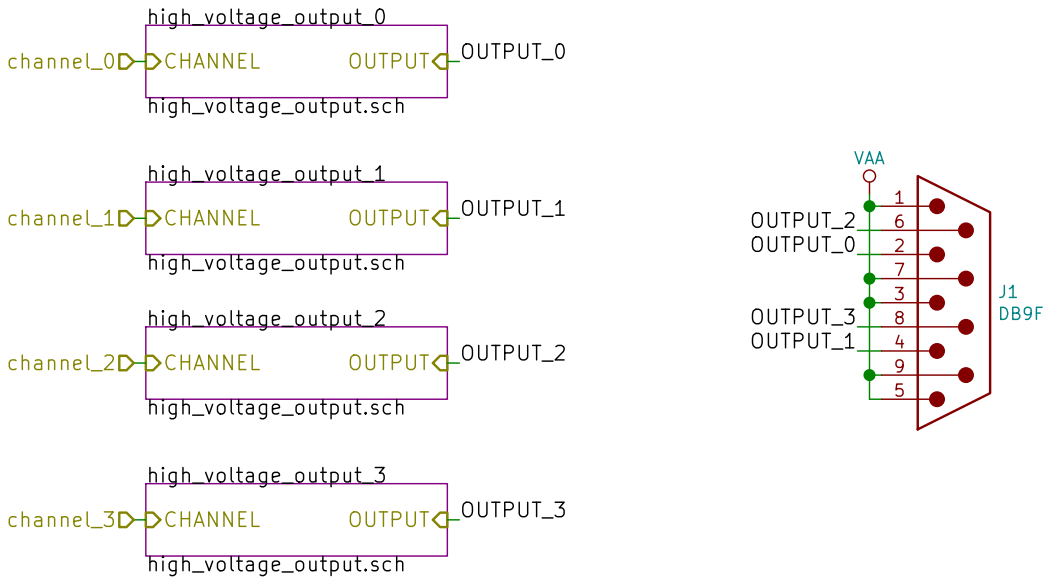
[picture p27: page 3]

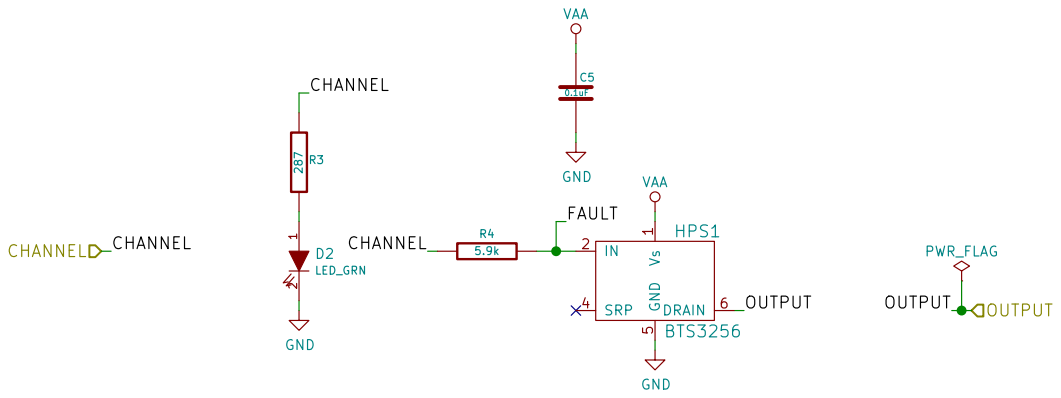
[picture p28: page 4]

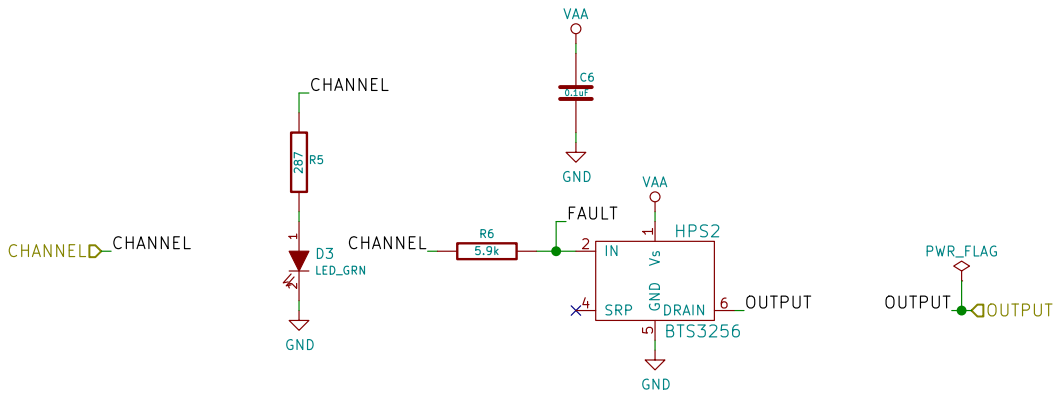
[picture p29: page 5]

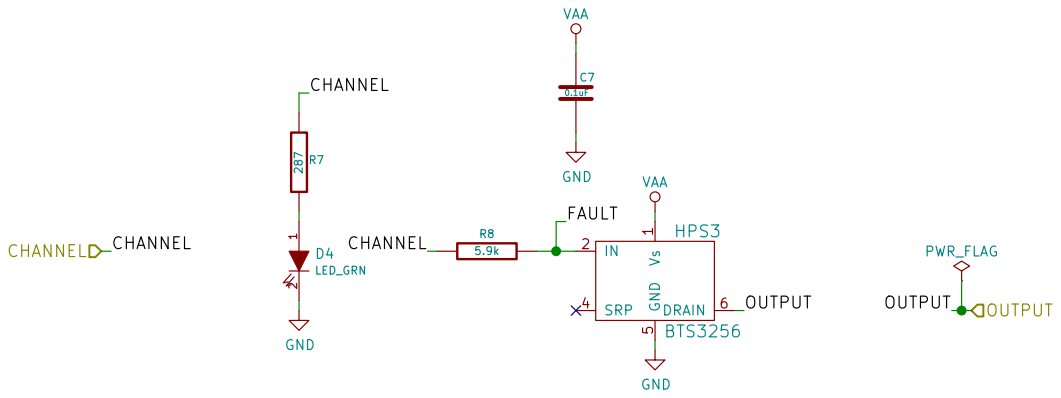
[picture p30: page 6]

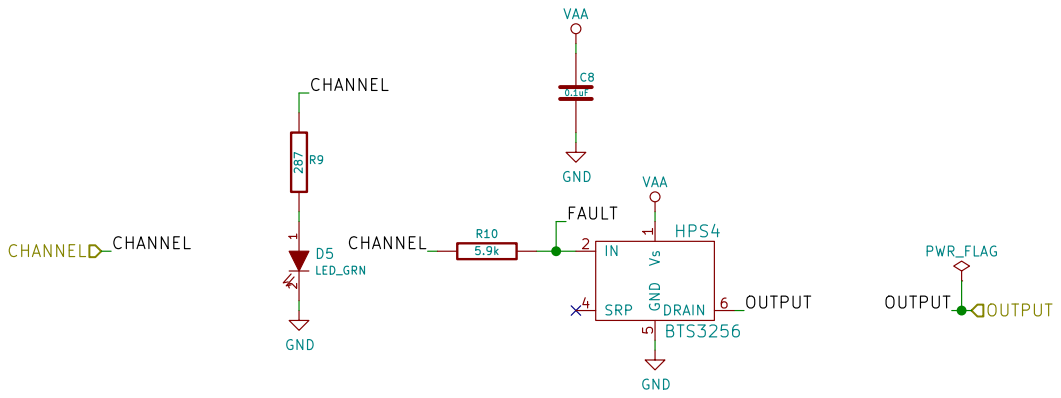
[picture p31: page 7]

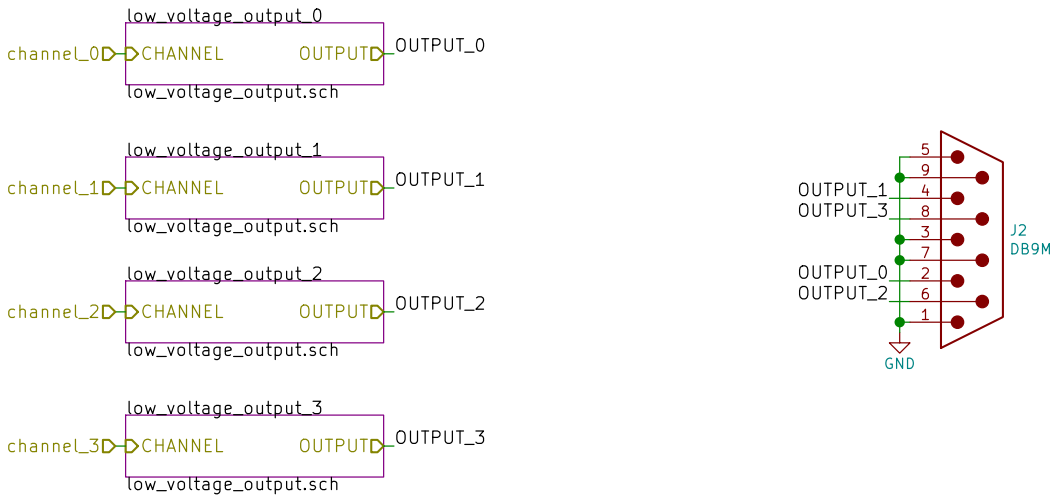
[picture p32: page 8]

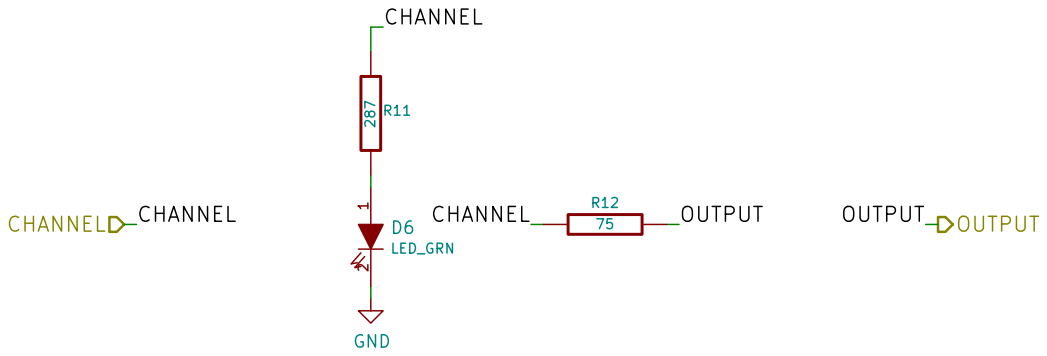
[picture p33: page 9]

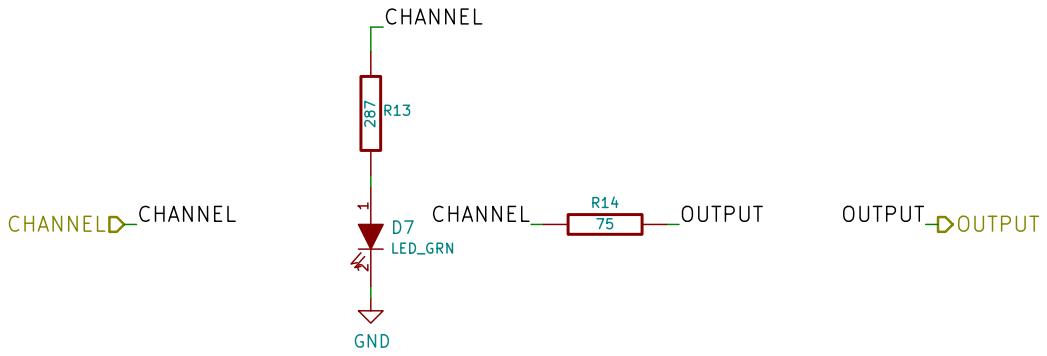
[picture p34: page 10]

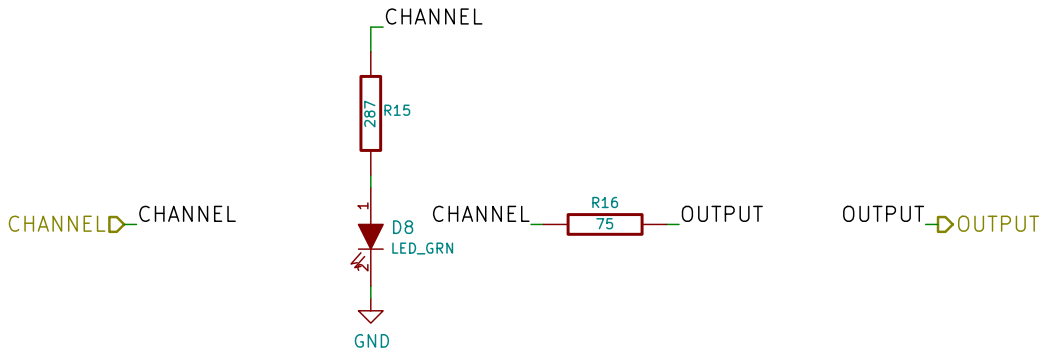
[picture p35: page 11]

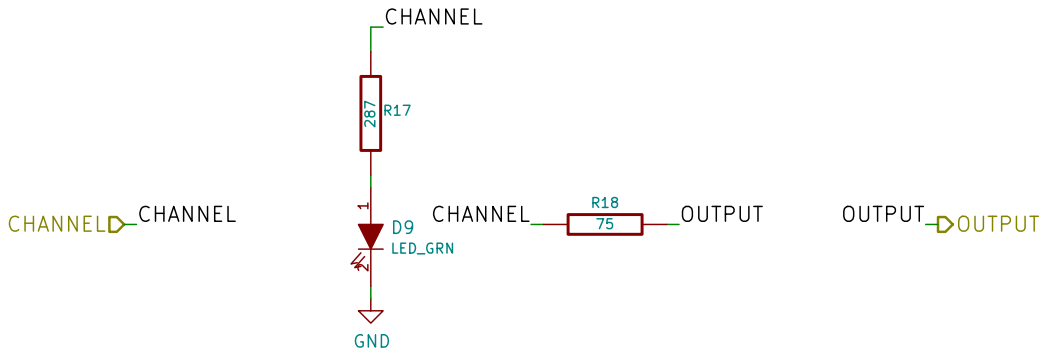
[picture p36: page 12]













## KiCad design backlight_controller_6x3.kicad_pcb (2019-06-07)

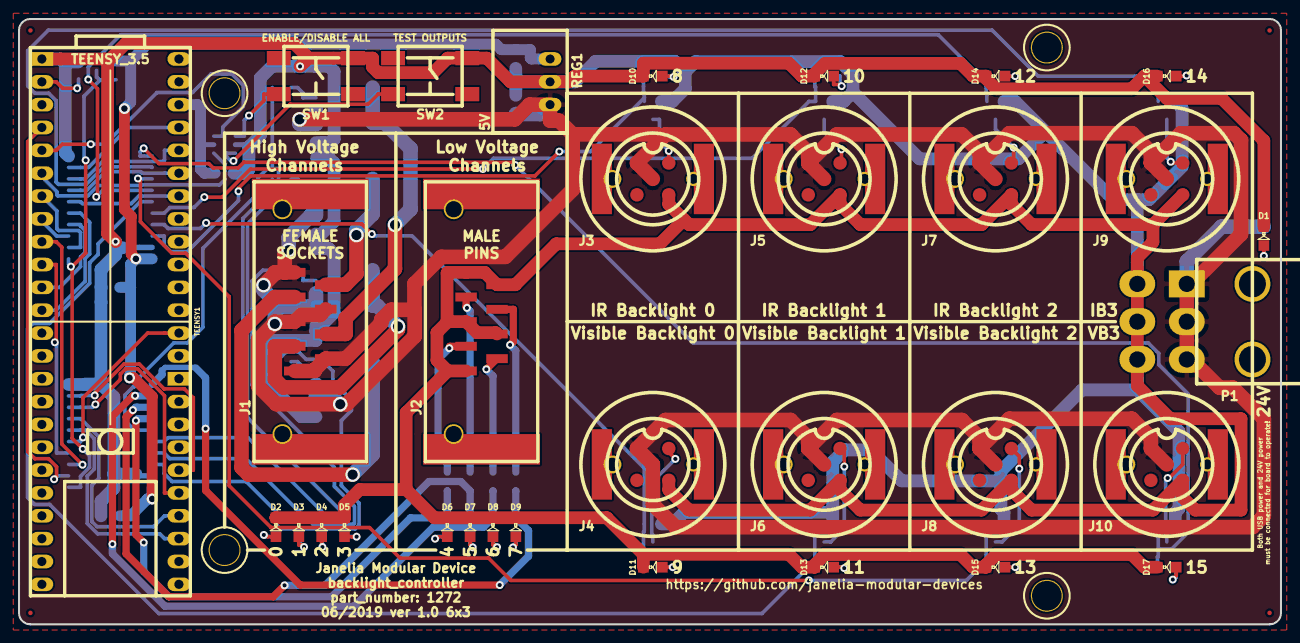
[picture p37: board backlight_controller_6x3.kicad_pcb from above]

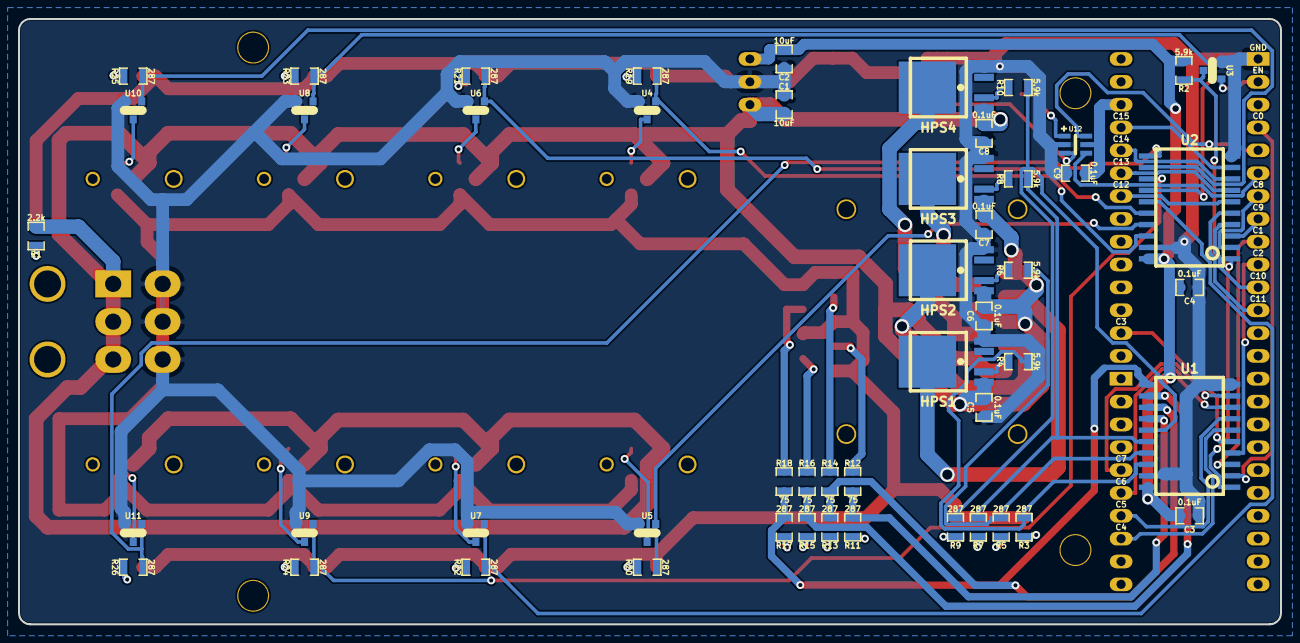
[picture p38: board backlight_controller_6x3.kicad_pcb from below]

Board: 2 copper layers, 140.3 x 67.3 mm, 91 parts (51 on the bottom side), 79 nets.

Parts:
C1, C2: 10uF; SM0805
C3, C4, C5, C6, C7, C8, C9: 0.1uF; SM0805
D1, D2, D3, D4, D5, D6, D7, D8, D9, D10, D11, D12, D13, D14, D15, D16, D17: LED_GRN; LED0805
FID1, FID2, FID3, FID4: FIDUCIAL
HPS1, HPS2, HPS3, HPS4: BTS3256; PG-TO252-5-11
J1: DB9F; DB9F_SMD
J2: DB9M; DB9M_SMD
J3, J4, J5, J6, J7, J8, J9, J10: M12-5-RCPT; M12-5_RCPT_F_SMD
MH1, MH2, MH3, MH4: MOUNTING_HOLE_4-40
P1: MINI_FIT; MINI-FIT-JR_02X03_M_RA
R1: 2.2k; SM0805
R2, R4, R6, R8, R10: 5.9k; SM0805
R3, R5, R7, R9, R11, R13, R15, R17, R19, R20, R21, R22, R23, R24, R25, R26: 287; SM0805
R12, R14, R16, R18: 75; SM0805
REG1: CONV_DC_DC_5V_1A; DC_DC_CONV_R78C
SW1, SW2: VAL**; SWITCH_KT
TEENSY1: TEENSY_3.5; TEENSY_3.5_MIN
U1, U2: SN74ABT541BDWR; SOIC_20
U3, U4, U5, U6, U7, U8, U9, U10, U11: NUD3124; TO-236-3
U12: VAL**; MAX6817

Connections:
+3V3: C9.1, TEENSY1.3V3, U12.5
/CHANNEL_0: TEENSY1.2, U1.2
/CHANNEL_1: TEENSY1.7, U1.3
/CHANNEL_2: TEENSY1.8, U1.4
/CHANNEL_3: TEENSY1.14, U1.5
/CHANNEL_4: TEENSY1.35, U1.6
/CHANNEL_5: TEENSY1.36, U1.7
/CHANNEL_6: TEENSY1.37, U1.8
/CHANNEL_7: TEENSY1.38, U1.9
/CHANNEL_8: TEENSY1.5, U2.2
/CHANNEL_9: TEENSY1.6, U2.3
/CHANNEL_10: TEENSY1.9, U2.4
/CHANNEL_11: TEENSY1.10, U2.5
/CHANNEL_12: TEENSY1.20, U2.6
/CHANNEL_13: TEENSY1.21, U2.7
/CHANNEL_14: TEENSY1.22, U2.8
/CHANNEL_15: TEENSY1.23, U2.9
/ENABLE: TEENSY1.0, U3.1
/backlight_6x3/C_0: R3.1, R4.1, U1.18
/backlight_6x3/C_1: R5.1, R6.1, U1.17
/backlight_6x3/C_2: R7.1, R8.1, U1.16
/backlight_6x3/C_3: R9.1, R10.1, U1.15
/backlight_6x3/C_4: R11.1, R12.1, U1.14
/backlight_6x3/C_5: R13.1, R14.1, U1.13
/backlight_6x3/C_6: R15.1, R16.1, U1.12
/backlight_6x3/C_7: R17.1, R18.1, U1.11
/backlight_6x3/C_8: R19.1, U2.18, U4.1
/backlight_6x3/C_9: R20.1, U2.17, U5.1
/backlight_6x3/C_10: R21.1, U2.16, U6.1
/backlight_6x3/C_11: R22.1, U2.15, U7.1
/backlight_6x3/C_12: R23.1, U2.14, U8.1
/backlight_6x3/C_13: R24.1, U2.13, U9.1
/backlight_6x3/C_14: R25.1, U2.12, U10.1
/backlight_6x3/C_15: R26.1, U2.11, U11.1
/backlight_6x3/backlight_outputs/ir_0/NPN: J3.2, U4.3
/backlight_6x3/backlight_outputs/ir_1/NPN: J5.2, U6.3
/backlight_6x3/backlight_outputs/ir_2/NPN: J7.2, U8.3
/backlight_6x3/backlight_outputs/ir_3/NPN: J9.2, U10.3
/backlight_6x3/backlight_outputs/visible_0/NPN: J4.2, U5.3
/backlight_6x3/backlight_outputs/visible_1/NPN: J6.2, U7.3
/backlight_6x3/backlight_outputs/visible_2/NPN: J8.2, U9.3
/backlight_6x3/backlight_outputs/visible_3/NPN: J10.2, U11.3
/backlight_6x3/high_voltage_outputs/OUTPUT_0: HPS1.6, J1.2
/backlight_6x3/high_voltage_outputs/OUTPUT_1: HPS2.6, J1.4
/backlight_6x3/high_voltage_outputs/OUTPUT_2: HPS3.6, J1.6
/backlight_6x3/high_voltage_outputs/OUTPUT_3: HPS4.6, J1.8
/backlight_6x3/high_voltage_outputs/high_voltage_output_0/FAULT: HPS1.2, R4.2
/backlight_6x3/high_voltage_outputs/high_voltage_output_1/FAULT: HPS2.2, R6.2
/backlight_6x3/high_voltage_outputs/high_voltage_output_2/FAULT: HPS3.2, R8.2
/backlight_6x3/high_voltage_outputs/high_voltage_output_3/FAULT: HPS4.2, R10.2
/backlight_6x3/low_voltage_outputs/OUTPUT_0: J2.2, R12.2
/backlight_6x3/low_voltage_outputs/OUTPUT_1: J2.4, R14.2
/backlight_6x3/low_voltage_outputs/OUTPUT_2: J2.6, R16.2
/backlight_6x3/low_voltage_outputs/OUTPUT_3: J2.8, R18.2
/backlight_6x3/~ENABLE: R2.2, U1.1, U2.1, U3.3
/modular_device_base_6x3_male/BTN_0: SW1.2, U12.1
/modular_device_base_6x3_male/BTN_0_D: TEENSY1.3, U12.6
/modular_device_base_6x3_male/BTN_1: SW2.2, U12.3
/modular_device_base_6x3_male/BTN_1_D: TEENSY1.4, U12.4
GND: C1.2, C2.2, C3.2, C4.2, C5.2, C6.2, C7.2, C8.2, C9.2, D1.2, D2.2, D3.2, D4.2, D5.2, D6.2, D7.2, D8.2, D9.2, D10.2, D11.2, D12.2, D13.2, D14.2, D15.2, D16.2, D17.2, HPS1.5, HPS2.5, HPS3.5, HPS4.5, J2.1, J2.3, J2.5, J2.7, J2.9, J3.3, J4.3, J5.3, J6.3, J7.3, J8.3, J9.3, J10.3, P1.4, P1.5, P1.6, REG1.2, SW1.3, SW2.3, TEENSY1.GND, U1.10, U1.19, U2.10, U2.19, U3.2, U4.2, U5.2, U6.2, U7.2, U8.2, U9.2, U10.2, U11.2, U12.2
unnamed: D1.1, R1.2
unnamed: D2.1, R3.2
unnamed: D3.1, R5.2
unnamed: D4.1, R7.2
unnamed: D5.1, R9.2
unnamed: D6.1, R11.2
unnamed: D7.1, R13.2
unnamed: D8.1, R15.2
unnamed: D9.1, R17.2
unnamed: D10.1, R19.2
unnamed: D11.1, R20.2
unnamed: D12.1, R21.2
unnamed: D13.1, R22.2
unnamed: D14.1, R23.2
unnamed: D15.1, R24.2
unnamed: D16.1, R25.2
unnamed: D17.1, R26.2
VAA: C1.1, C5.1, C6.1, C7.1, C8.1, HPS1.1, HPS2.1, HPS3.1, HPS4.1, J1.1, J1.3, J1.5, J1.7, J1.9, J3.1, J3.5, J4.1, J4.5, J5.1, J5.5, J6.1, J6.5, J7.1, J7.5, J8.1, J8.5, J9.1, J9.5, J10.1, J10.5, P1.1, P1.2, P1.3, R1.1, REG1.1
VEE: C2.1, C3.1, C4.1, R2.1, REG1.3, U1.20, U2.20

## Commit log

2019-06-04 Update version documentation
    [backlight_6x3.sch, backlight_controller_6x3.kicad_pcb, backlight_controller_6x3.sch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]
2019-06-04 Progress towards v1.0
    [backlight_6x3.sch, backlight_controller_6x3.sch, backlight_output.sch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]
2019-06-05 Add enable pullup resistor
    [backlight_6x3.sch, backlight_controller_6x3.sch]
2019-06-06 Route board
    [backlight_controller_6x3.dsn, backlight_controller_6x3.kicad_pcb]
2019-06-07 Route board and generate gerbers
    [backlight_controller_6x3-B_Cu.gbl, backlight_controller_6x3-B_Mask.gbs, backlight_controller_6x3-B_Paste.gbp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]
2019-06-07 Update documentation
    [Digi-Key_parts.csv, bom.csv]
2021-09-21 Remove ignored files
    [backlight_controller_6x3.dsn]
